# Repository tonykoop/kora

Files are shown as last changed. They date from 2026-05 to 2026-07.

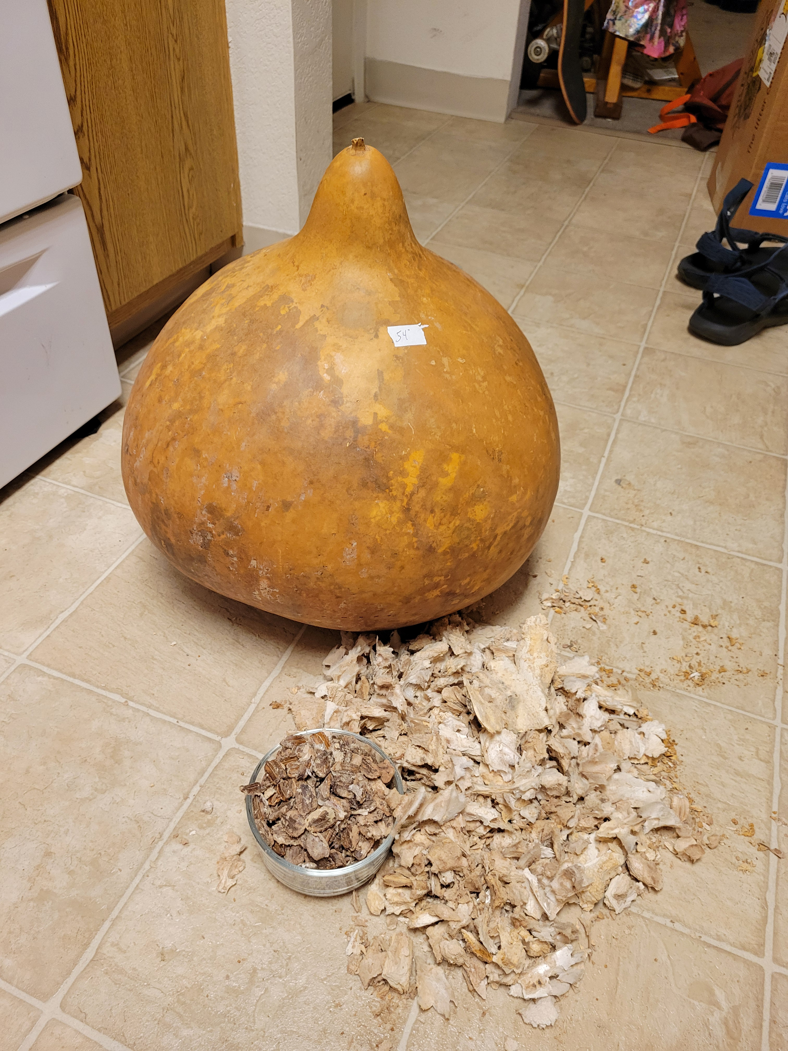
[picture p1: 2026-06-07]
projects/new kora build/20260530_212532.jpg

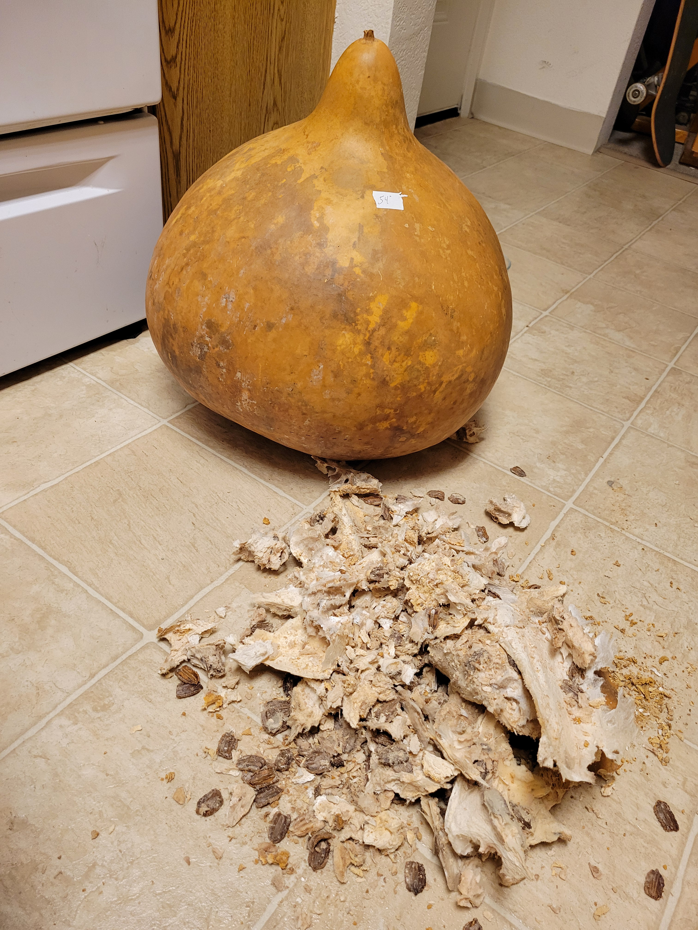
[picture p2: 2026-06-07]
projects/new kora build/20260530_210344.jpg

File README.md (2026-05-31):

# Kora Root-Mode Build Packet

**Status: L2 V5 build-packet candidate**

This repo is a root-mode v4 instrument packet for a 21-string kora-inspired build. It expands the original bare design-table scaffold into a shop-facing packet with design notes, BOM, sourcing assumptions, cut list, validation plan, drawing briefs, RFQ copy, public-site draft, capstone outline, and print packet.

The design source is `kora-design-table.xlsx`. The workbook currently provides the main parametric anchors: bowl diameter and depth, neck length, string lengths, target string tension ramp, nylon density, wound-string density factor, segmented-bowl ring construction, rim geometry, bridge dimensions, and string spacing. Several cell meanings are inferred from formulas rather than workbook labels, so the generated documents mark those assumptions openly.

## Public Release Status

This packet should stay private pending cultural and build-safety review. The kora is not just a generic harp-like mechanism; it belongs to West African Mande/Mandinka musical traditions and is historically associated with jali/griot musicianship. This repo documents an engineering prototype and does not claim lineage authority, traditional build certification, repertoire authority, or permission to market the instrument as culturally authentic.

Before public release, review the provenance language with a knowledgeable cultural advisor or kora player, replace placeholder visuals with measured shop photos or respectful diagrams, and confirm that licensing terms do not accidentally imply cultural ownership.

## Packet Map

- `design.md` - design intent, workbook interpretation, assumptions, cultural provenance notes, and physics model.
- `family-spec.csv` - root build plus lower-risk study variants for future iteration.
- `bom.csv` - make/buy material and hardware list with estimated costs marked as planning estimates.
- `sourcing.csv` - spec-first sourcing table with live price and availability intentionally not verified.
- `cut-list.csv` - rough/final dimensions for segmented bowl, neck, bridge, handles, fixtures, and templates.
- `validation.csv` - dimensional, string-tension, resonance, bridge, joint, safety, and cultural-review checks.
- `string-validation.md` and `string-break-risk.csv` - explicit string break-risk blocker and row-by-row full-stringing gates.
- `assembly-manual.md` - staged build method with hold points before full tension.
- `supplier-rfq.md` - copy/paste RFQ drafts for wood, hide/head material, strings, metalwork, and pickup parts.
- `drawing-brief.md` and `visual-bom-brief.md` - drawing and visual-resource requirements.
- `kora-starter.wl` - starter calculations for string schedule, segmented bowl geometry, and safety plots.
- `risks.md` - red-team concerns and release controls.
- `photo-shotlist.md` - shop and documentation shot list.
- `capstone-deck.md`, `capstone-manifest.json` - presentation outline and artifact inventory.
- `print-packet.md`, `print-packet.html` - print-friendly packet for shop review.
- `site/index.html` - self-contained public build-log draft, currently marked private-review.
- `drawings/`, `cad/`, `cnc/`, `wolfram/` - lightweight technical placeholders and briefs.
- `review-evidence.md` - PR review evidence, local checks, and readiness summary.

## Workbook Snapshot

Current interpreted values from `kora-design-table.xlsx`:

- Bowl outer diameter: 20.3 in.
- Bowl depth: 9.8 in.
- Neck length: 51.2 in.
- String vibrating lengths: 8.7 to 31.1 in.
- Target tension ramp: 8.0 to 14.0 lbf per string.
- Nylon density: 0.04155 lb/in^3.
- Wound-string effective density factor: 2.5x.
- Segmented bowl: 12 segments per ring, 15 deg miter, 0.75 in ring thickness, 14 rings, 168 total segments.
- Bridge height: 6.0 in, bridge width/thickness inputs around 0.75 and 2.5 in, string spacing about 0.273 in by formula.

The current string schedule computes some treble strings at high percent of nylon break strength under the ideal round-string model. Treat the schedule as a design-study table, not a purchase-ready string prescription.

Round 33C/D string validation adds `string-break-risk.csv`: eight nylon rows currently model above the 70 percent prototype break target, nylon string 9 sits at 69.3 percent, and the wound-bass rows still need manufacturer unit-weight or measured mass-per-length data. Full stringing remains blocked until those rows are revised and rechecked.

## Cultural Provenance Notes

External background sources consulted for the provenance framing include the Met Museum collection notes on Mandinka kora objects and Britannica's kora overview. These sources are used only to avoid careless wording; they do not substitute for community review or living maker/player expertise.

- Met Museum kora object notes: https://www.metmuseum.org/art/collection/search/501115
- Britannica kora overview: https://www.britannica.com/art/kora-musical-instrument

## Build Position

This is a conservative hybrid prototype packet:

- A segmented wooden bowl is documented as a calabash substitute, not a traditional-material claim.
- Hide or synthetic head choices are treated as separate resonance and ethics/sourcing decisions.
- A piezo pickup path is planned as optional and should be mechanically isolated from the head until acoustic behavior is understood.
- The neck/body joint, bridge foot, tail anchoring, and head support are treated as primary safety-critical assemblies.

## Readiness

Status: L2 private-review packet. The docs are broad enough for design review, but the packet should not be treated as L3 until cultural review, string-safety revisions, bridge/head proof testing, and measured prototype data are complete.

## License

[CC BY 4.0](LICENSE) - see `LICENSE` for details. Public sharing should wait until the review gates in `risks.md` and `validation.csv` are resolved.

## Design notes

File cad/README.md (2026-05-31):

# `cad/` — CAD assets for the kora-inspired 21-string prototype

## What's here

### SolidWorks source
| File | What it is |
| --- | --- |
| `KOR-000_MasterLayout.SLDPRT` | Parametric MasterLayout part. Source of truth for every driven dimension; design table lives in `KOR-000_MasterLayout.xlsx`. |
| `KOR-000_MasterLayout.xlsx` | Design table (read by SolidWorks). |
| `KOR-000_KoraHarp.SLDASM` | Assembly tying MasterLayout to the part files below. |
| `KOR-000_KoraHarp_ALL_CONFIGS_dimensions.csv` | Flat export of every driven dimension across all configurations. |
| `KOR-000-Gourd.SLDPRT` | Segmented hardwood bowl (168-stave substitute for calabash). |
| `KOR-000-Neck.SLDPRT` | Through-neck spine — continuous structural load path. |
| `KOR-000-Crossbar.SLDPRT` | Neck-to-rim cross brace. |
| `KOR-000-Handle.SLDPRT` | Player hand post (instanced twice in the assembly). |
| `KOR-000-Membrane.SLDPRT` | Hide or synthetic head. |
| `KOR-000-BridgePad.SLDPRT` | Bridge foot pad / cushion against membrane. |
| `KOR-000-Bridge.SLDPRT` | 6.0″ tall notched bridge, two string banks. |
| `KOR-000-Eyebolt.SLDPRT` | Tail anchor (load-rated, rounded contact surfaces). |
| `7815K21_Multipurpose Flanged Sleeve Bearing.SLDPRT` | McMaster-Carr sleeve bearing (×2). |
| `7815K24_High-Strength 932 Bronze Flanged Sleeve Bearing.SLDPRT` | Alternate sleeve bearing for upgrade path. |
| `3032T43_316 Stainless Steel Eyebolt with Nut.SLDPRT` | Stock eyebolt for reference / sourcing. |
| `KOR-000-BasePartTemplate.SLDPRT` | Base part template used to spawn new instances. |
| `kora-parametric-brief.md` | Plain-English brief listing parameters to import from the workbook + CAD warnings. |
| `kora-placeholder.scad` | OpenSCAD placeholder kept for cross-tool reference. |
| `~$…` files | SolidWorks lockfiles — leave alone, they vanish when SW closes the file. |

### glTF export (for the web explorer)
| File / path | What it is |
| --- | --- |
| `KOR-000_KoraHarp/KOR-000_KoraHarp.gltf` | glTF 2.0 JSON metadata. The web explorer (`../explorer.html`) loads this directly via `<model-viewer>`. |
| `KOR-000_KoraHarp/0-N-<part>-N.bin` | One binary buffer per assembly component — 11 buffers total, one per assembly instance (Neck, Gourd, both Handles, Membrane, BridgePad, Bridge, Crossbar, Eyebolt, two Sleeve Bearings). |
| `KOR-000_KoraHarp/leather.jpg` | Texture map for the membrane part. |

## How `explorer.html` consumes the glTF

`explorer.html` (one level up at the repo root) inline-embeds the model as a base64 data URI so the page is fully self-contained — double-click works, no localhost server required.

The packed `KOR-000_KoraHarp.glb` (~971 KB, DRACO-compressed; ~1.3 MB once base64-encoded) lives in a `<script id="kora-glb-data">` tag at the top of the body, and a small `injectCADModel()` function assigns it as the `<model-viewer>` element's `src` on boot. The `images/SolidWorks QuadView.png` four-view shot displays as the poster until the model finishes decoding.

This is the inline-first arrangement (chose 2026-05-17 to make `explorer.html` work as a portable single file). Trade-off: the HTML is ~1.4 MB instead of ~80 KB. Acceptable since the explorer is already not pure-offline (the Wolfram embed iframe + the `model-viewer` JS itself load from CDNs).

If the inline embed gets too heavy later, fall back to either:
- Reference the `.glb` as an external file: `<model-viewer src="cad/KOR-000_KoraHarp.glb">` — requires localhost serving (`python -m http.server 8000` from the kora dir), but trims the HTML back to ~80 KB.
- Reference the multi-buffer glTF directly: `<model-viewer src="cad/KOR-000_KoraHarp/KOR-000_KoraHarp.gltf">` — also requires localhost serving, plus 12 same-origin fetches.

## Re-exporting from SolidWorks → re-packing → re-embedding

When the assembly changes (final details still to come per the v4.3 challenge run), the round-trip is:

1. Open `KOR-000_KoraHarp.SLDASM` in SolidWorks (2024+ has glTF export built in; older versions need an add-in).
2. **File → Save As → glTF 2.0 (`*.gltf`)**. Save into `cad/KOR-000_KoraHarp/` and overwrite the existing files. (`.glb` direct from SolidWorks also works but skips the DRACO-compression step below.)
3. Re-pack the multi-buffer glTF into a single DRACO-compressed `.glb`:
   ```bash
   npx -p gltf-pipeline gltf-pipeline \
       -i cad/KOR-000_KoraHarp/KOR-000_KoraHarp.gltf \
       -o cad/KOR-000_KoraHarp.glb -b -d
   ```
   The `-b` flag asks for a single binary `.glb`; `-d` adds DRACO compression (typically 60–70 % size reduction).
4. Re-base64-embed the new `.glb` into `explorer.html`. Until the instrument-maker skill's generator pass lands, this is a small Python script:
   ```python
   import base64, pathlib
   glb = pathlib.Path("cad/KOR-000_KoraHarp.glb").read_bytes()
   uri = "data:model/gltf-binary;base64," + base64.b64encode(glb).decode()
   src = pathlib.Path("explorer.html").read_text(encoding="utf-8")
   # Replace whatever URI is between the kora-glb-data script tags.
   import re
   src = re.sub(r'(__KORA_GLB_DATA_URI__ = ")[^"]+(")', r'\1' + uri + r'\2', src, count=1)
   pathlib.Path("explorer.html").write_text(src, encoding="utf-8")
   ```
   Once the generator ships, this becomes `python scripts/generate_explorer.py kora`.

## TODOs (non-blocking)

- **Reduce buffer count.** SolidWorks emits one .bin per assembly instance. A `.glb` re-export or a downstream `gltf-pipeline` pass would pack everything into a single binary — smaller wire size, simpler serving.
- **Material assignments.** Current export uses default materials (the only custom map is `leather.jpg` on the membrane). Worth a pass to assign walnut / cedar / brass / nylon-strings PBR materials in SolidWorks Appearances before re-export, so the in-browser model matches the build palette.
- **String geometry.** Strings are present as edges in the SolidWorks model but may render thin / unlit in glTF. A `gltf-pipeline` thicken pass or an explicit cylinder swap would help.
- **Desktop-Wolfram re-author pass.** Independent of CAD, but tracked alongside: `kora-starter.wl` is authored on the WSL Wolfram Engine CLI. A future re-author pass in Wolfram 14.3 desktop (Windows side) could give richer `Manipulate` output before the `wolfram-cloud-sync` Public-Execute publish step.

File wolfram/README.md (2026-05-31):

# Wolfram Notes

Two notebooks live in this folder + repo root:

- `kora-starter.wl` (repo root) — first-pass string and segmented-bowl checks against the workbook string schedule. Workbook-driven.
- `wolfram/kora-acoustic-design.wl` — physics-bounded acoustic design notebook. Computes Helmholtz air resonance, membrane modes, bridge placement coupling, and string schedule from the SolidWorks masterLayout's measured geometry. Use this to sweep chord factor, sound hole size, and bridge offset before committing the masterLayout.

## Running in Wolfram Cloud

1. Open `https://www.wolframcloud.com`, create a new notebook.
2. Paste the contents of `kora-acoustic-design.wl` into a single input cell.
3. Shift+Enter to evaluate. All printouts, tables, and plots render inline.
4. To sweep a parameter, edit the relevant variable in Section 1 (e.g., `chordFactor = 0.50`) and re-evaluate.

## Future notebook exports should include

- revised low-tension mule schedule
- bowl ring geometry table
- measured vs predicted frequency chart
- bridge/head deflection measurements
- post-build tap-test results vs Section 7 predicted Helmholtz and membrane fundamental

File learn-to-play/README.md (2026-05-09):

# Kora — Learn to Play

Starter songbook for Tony Koop's kora build.

## About the kora

The kora is a 21-string West African harp-lute from the Mande tradition
(Gambia, Senegal, Guinea, Mali). It is played with both thumbs and index
fingers; the other fingers grip the handles on either side of the gourd body.

## Tuning

Standard **"Tomora Bara"** tuning in F major pentatonic. Strings are arranged
in two interlocking rows (left and right), not in linear pitch order.

**Left-hand bridge strings (thumb L + index L):**

| String | Pitch |
|---|---|
| L1 | F3 |
| L2 | A3 |
| L3 | C4 |
| L4 | F4 |
| L5 | A4 |
| L6 | C5 |
| L7 | F5 |
| L8 | A5 |
| L9 | C6 |
| L10 | F6 |
| L11 | A6 |

**Right-hand bridge strings (thumb R + index R):**

| String | Pitch |
|---|---|
| R1 | G3 |
| R2 | Bb3 |
| R3 | D4 |
| R4 | G4 |
| R5 | Bb4 |
| R6 | D5 |
| R7 | G5 |
| R8 | Bb5 |
| R9 | D6 |
| R10 | G6 |

(Standard Tomora Bara uses F major pentatonic as the tonal centre; the G and
Bb strings add colour tones from the Bb major scale context.)

## Notation

Staff notation in treble clef. No TAB (the kora is not a fretted instrument).
Melodies are notated at sounding pitch.

## Repertoire

| Folder | Tune | Difficulty |
|---|---|---|
| `00-warmup-scales/f-pentatonic/` | F Pentatonic Scale Walk | Warmup |
| `01-easy/kaira-pattern/` | Kaira Pattern | Easy |
| `01-easy/kora-bells/` | Kora Bells (exercise) | Easy |
| `02-intermediate/tutu-jara-motif/` | Tutu Jara Motif | Intermediate |
| `03-original/river-crossing/` | River Crossing | Intermediate |

## Technique

- Strings are plucked outward (away from the gourd) with the pad of the thumb
  or the nail-side of the index finger.
- Alternating thumb and index finger produces the characteristic kora shimmer.
- Louder notes come from more snap speed, not more force — a sharp, quick
  release produces a bell-like tone.

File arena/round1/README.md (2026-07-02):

# Arena winner: kora (round1)

**Generated model** — the winning Code-CAD Arena candidate for this
instrument (entrant `antigravity-gemini-default`, blind-vote wins 2.0, objective pass-rate 0.5).

This is an AI-generated arena artifact, NOT a measured master or a
validated build packet. See `provenance.json` for the full trial
record. Exported by `makerbench arena export-winners`.

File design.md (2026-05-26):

# Kora Root-Mode Design

## Intent

Create a serious build packet for a 21-string kora-inspired hybrid instrument using `kora-design-table.xlsx` as the parametric design source. The intended first build is a learning prototype, not a declaration of traditional authority or a production-ready commercial instrument.

The packet balances six coupled systems:

- string scaling and tension
- tall notched bridge geometry
- hide or membrane-loaded resonator behavior
- neck load path and tail anchoring
- player ergonomics and hand access
- cultural provenance and public-release sensitivity

## Scope Boundary

This packet documents an engineering prototype rooted in measured and parametric assumptions. It does not claim exact acoustic prediction, traditional craft certification, historical completeness, or permission to present the result as an authentic cultural object. The first release should be private until the cultural-review and safety gates in `validation.csv` pass.

## Workbook Source

Source workbook: `kora-design-table.xlsx`, sheet `Kora`.

The workbook is currently a compact formula sheet without visible human-readable row labels. The following interpretations are inferred from cell values and formulas and should be confirmed before CNC or string purchasing:

| Workbook area | Interpreted meaning | Current value or formula |
| --- | --- | --- |
| `B5` | Bowl outside diameter | 20.3 in |
| `B6` | Bowl depth | 9.8 in |
| `B7` | Neck length | 51.2 in |
| `B8:B9` | Shortest and longest string lengths | 8.7 in, 31.1 in |
| `B10:B11` | Target string tension ramp | 8.0 to 14.0 lbf |
| `B12` | Nylon density | 0.04155 lb/in^3 |
| `B13` | Wound-string effective density factor | 2.5x |
| `B14` | Wound-string start index | 18 |
| `B19:B24` | Segmented bowl setup | 12 segments/ring, 0.75 in ring height, 14 rings, 168 segments |
| `B45:B50` | Rim setup | 16 segments, 11.25 deg miter, 0.5 in rim thickness input |
| `B83:B88` | Bridge setup | 2.5 in/6.0 in/0.75 in inputs, 0.125 in slot clearance, 0.273 in spacing |
| Rows `59:79` | 21-string pitch/length/tension schedule | Mersenne-Taylor formulas |

## Cultural Provenance

The kora is widely documented as a West African 21-string bridge-harp/harp-lute associated with Mande/Mandinka traditions and jali/griot musicianship. The Met Museum collection notes describe the kora as a 21-string instrument from the Mande region with a calabash resonator, hide soundboard, long neck, handles, and a tall bridge. Britannica similarly describes a long hardwood neck passing through a hide-covered calabash resonator, with 21 strings over a notched bridge.

Design language for this repo should therefore use terms such as `kora-inspired prototype`, `engineering study`, and `hybrid build packet`. Avoid wording such as `authentic`, `traditional replica`, `master kora`, or `improved kora`.

Background sources:

- https://www.metmuseum.org/art/collection/search/501115
- https://www.britannica.com/art/kora-musical-instrument

## Governing Models

### Strings

Use the Mersenne-Taylor string model:

```text
f = (1 / (2 L)) sqrt(T / mu)
mu = density pi (diameter / 2)^2
diameter = 2 sqrt(T g / (density pi 4 L^2 f^2))
```

Workbook constants:

- `g = 386.4 in/s^2`
- nylon density = `0.04155 lb/in^3`
- assumed nylon breaking stress = `44600 psi`
- wound-string effective density factor = `2.5x`

Important limitation: percent break is independent of diameter in the ideal round-string model. The current workbook schedule calculates several treble strings near or above practical nylon break targets. This is a safety and design-readiness issue, not a cosmetic issue.

### Resonator

The workbook models a segmented wooden bowl replacing a natural calabash. This changes mass, stiffness, damping, and attachment options. Do not treat the bowl as acoustically equivalent to a traditional calabash without measurements.

The first prototype should measure:

- open bowl air resonance before head installation
- head tap modes after skin or synthetic membrane installation
- bridge-loaded head deflection at staged tension
- microphone response before and after optional piezo installation

### Bridge

The bridge is load-bearing and tone-shaping. It must separate two string banks, maintain string notch spacing, transfer load into the head without tearing it, and avoid rocking under asymmetric playing loads.

Workbook bridge hints:

- height: 6.0 in
- width/thickness inputs: 0.75 in and 2.5 in, to confirm by drawing
- slot clearance: 0.125 in
- string spacing formula: `6 / (21 + 1) = 0.273 in`

### Neck And Load Path

The neck is interpreted as 51.2 in long. A traditional neck passes through the resonator; this hybrid packet should preserve a continuous structural load path rather than relying on the bowl wall alone.

Minimum first-build requirement:

- continuous neck or internal spine through the bowl
- separate tail ring or tail bar with mechanical backup
- no full string load until joint proof-load and bridge-foot tests pass

## Current String Schedule

The schedule below is calculated from the workbook formula pattern and current constants. It is a planning table, not a purchase-ready prescription.

| # | Note | MIDI | Freq Hz | Length in | Type | Target lbf | Diameter in | Percent break |
| ---: | --- | ---: | ---: | ---: | --- | ---: | ---: | ---: |
| 1 | D6 | 86 | 1174.66 | 8.70 | Nylon | 8.00 | 0.0151 | 100.7 |
| 2 | C6 | 84 | 1046.50 | 9.40 | Nylon | 8.30 | 0.0159 | 93.3 |
| 3 | A#5 | 82 | 932.33 | 10.20 | Nylon | 8.60 | 0.0168 | 87.2 |
| 4 | A5 | 81 | 880.00 | 11.00 | Nylon | 8.90 | 0.0168 | 90.4 |
| 5 | G5 | 79 | 783.99 | 12.00 | Nylon | 9.20 | 0.0175 | 85.4 |
| 6 | F5 | 77 | 698.46 | 13.00 | Nylon | 9.50 | 0.0185 | 79.5 |
| 7 | E5 | 76 | 659.26 | 13.80 | Nylon | 9.80 | 0.0187 | 79.8 |
| 8 | D5 | 74 | 587.33 | 15.00 | Nylon | 10.10 | 0.0196 | 74.9 |
| 9 | C5 | 72 | 523.25 | 16.20 | Nylon | 10.40 | 0.0207 | 69.3 |
| 10 | A#4 | 70 | 466.16 | 17.50 | Nylon | 10.70 | 0.0218 | 64.2 |
| 11 | A4 | 69 | 440.00 | 18.50 | Nylon | 11.00 | 0.0222 | 63.9 |
| 12 | G4 | 67 | 392.00 | 19.80 | Nylon | 11.30 | 0.0236 | 58.1 |
| 13 | F4 | 65 | 349.23 | 21.20 | Nylon | 11.60 | 0.0250 | 52.9 |
| 14 | E4 | 64 | 329.63 | 22.50 | Nylon | 11.90 | 0.0253 | 53.0 |
| 15 | D4 | 62 | 293.66 | 24.00 | Nylon | 12.20 | 0.0270 | 47.9 |
| 16 | C4 | 60 | 261.63 | 25.50 | Nylon | 12.50 | 0.0288 | 42.9 |
| 17 | A#3 | 58 | 233.08 | 27.00 | Nylon | 12.80 | 0.0309 | 38.2 |
| 18 | A3 | 57 | 220.00 | 28.20 | Wound | 13.10 | 0.0201 | 92.8 |
| 19 | G3 | 55 | 196.00 | 29.50 | Wound | 13.40 | 0.0218 | 80.6 |
| 20 | F3 | 53 | 174.61 | 30.50 | Wound | 13.70 | 0.0239 | 68.4 |
| 21 | F3 | 53 | 174.61 | 31.10 | Wound | 14.00 | 0.0237 | 71.1 |

Action: reduce treble target tension, lengthen treble scale, change material, or revise pitch assignment before stringing to full pitch. `string-break-risk.csv` is the row-by-row blocker register for this schedule, and `string-validation.md` defines the full-stringing hold points.

## Design Assumptions

- The segmented bowl is a practical shop substitute for calabash, not a cultural or acoustic equivalence claim.
- Neck stock is a straight-grained hardwood blank, final species to be selected for strength and workability.
- Head material is either ethically sourced hide or a synthetic membrane selected after supplier review.
- The first bridge is sacrificial and should be built with extra footprint options for testing.
- The first stringing uses a staged low-tension mule schedule before final target pitches.
- Optional piezo pickup is installed only after the acoustic bridge/head behavior is known.

## Done Criteria

- Workbook labels are clarified or a companion cell map is added.
- Bridge and neck load path are drawn with dimensions, tolerances, and proof-load method.
- String schedule passes percent-break and handling checks.
- Head material and attachment method are sourced with ethical and safety notes.
- Cultural review confirms that public wording is respectful and not overclaiming.
- A measured prototype updates `validation.csv` and the workbook.

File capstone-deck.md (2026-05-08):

# Title

Kora-Inspired 21-String Prototype Root Packet

Private v4.3 challenge run focused on string scaling, segmented resonator construction, bridge geometry, neck load path, ergonomics, and respectful provenance.

# Project Intent

Build a serious engineering packet for a kora-inspired hybrid prototype while preserving humility around cultural context. The packet is intended for private design review, shop planning, and validation before any public build-log release.

# File Map

README, design notes, structured CSVs, sourcing, cut list, validation, assembly manual, RFQ, drawing brief, visual BOM brief, Wolfram starter, risks, photo shotlist, print packet, static site draft, and drawing/CAD/CNC placeholders all live at repo root or first-level folders.

# Workbook Source

The parametric source is `kora-design-table.xlsx`. It provides bowl, neck, string, bridge, and segmented construction values. Some cell meanings are inferred from formulas because the workbook is compact and minimally labeled.

# Governing Physics

The string schedule uses Mersenne-Taylor formulas. Resonator and head behavior are treated as empirical because the segmented wood bowl and membrane/bridge loading cannot be predicted accurately from simple formulas alone.

# String Safety

The current workbook schedule produces high percent-break values in the treble and modeled wound-bass range. This is the largest immediate design risk and requires a low-tension mule schedule before full stringing.

# Resonator And Head

The bowl is modeled as a 20.3 in diameter, 9.8 in deep segmented wooden calabash substitute with 14 rings and 168 segments. It is not presented as a traditional material equivalent.

# Bridge Geometry

The bridge is a tall notched load-transfer part. Its foot, notch spacing, bank separation, and rocking resistance must be validated before tuning targets matter.

# Neck And Tail Load Path

The neck is interpreted from the workbook as 51.2 in long. The first build requires a continuous through-neck or internal spine and a load-rated tail anchor rather than relying on bowl wall strength.

# BOM And Sourcing

The BOM is spec-first. Live prices, stock, and lead times are not verified. Supplier RFQs ask for material traceability, string data, ethical head sourcing, and load-rated hardware.

# Assembly Workflow

Build sequence: workbook audit, segmented bowl, rim/head interface, neck and tail proof-load, bridge prototype, low-tension stringing, measurement, then optional pickup.

# Validation

Validation covers cultural wording, workbook traceability, string safety, miter accuracy, bowl integrity, neck/tail proof load, bridge pressure, tuning, resonator response, ergonomics, and visual placeholder labeling.

# Risks

Primary risks are cultural overclaiming, string breakage, bridge rocking, head tearing, neck/body joint failure, tail anchor cutting, humidity movement, and ergonomics.

# Public Release

This repo should remain private pending cultural review, safety validation, measured prototype data, and replacement of placeholder visuals with owned photos or clearly labeled schematics.

# Next Actions

Label workbook cells, revise the string schedule with real unit-weight data, build a low-tension bridge/head mule, proof-load the neck/tail system, and request cultural wording review.

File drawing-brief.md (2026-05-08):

# Drawing Brief

## Required Drawing Set

1. `drawings/kora-overview.svg` - whole-instrument orthographic overview with bowl diameter, bowl depth, neck length, bridge height, string length range, centerline, and tail anchor.
2. `drawings/bowl-ring-stack.svg` - segmented bowl profile with 14 rings, 12 segments per ring, 15 deg miter note, and depth datum.
3. `drawings/bridge-geometry.svg` - bridge blank, notch spacing, split-bank concept, foot pad, and warning that exact bank layout needs player review.
4. `drawings/load-path-section.svg` - neck/spine, tail anchor, bridge/head load, and bowl wall bypass.
5. `drawings/head-retention-detail.svg` - tacked, laced, or hoop variants after material choice.
6. `drawings/ergonomic-player-view.svg` - seated playing posture with hand posts and wrist-risk zones.

## Technical Standard

Every build-critical drawing should include:

- title block, date, revision, units in inches
- workbook source cell references
- centerline and bridge/tail datums
- dimensions and tolerances separated into fit-critical, load-critical, and visual
- material assumptions
- validation hold points

## Current Status

The SVG files in `drawings/` are lightweight briefs/placeholders. They are not CNC-ready drawings. Use them to coordinate CAD and shop review, then replace them with dimensioned CAD exports before public release or machining.

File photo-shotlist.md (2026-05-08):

# Photo Shotlist

## Provenance And Context

- Workbook open on the `Kora` sheet, showing the design source.
- Printed packet with private-review label visible.
- Material samples labeled as prototype substitutes, not traditional claims.

## Shop Process

- Hardwood stock before cutting.
- Miter sled setup at 15 deg.
- First 12-segment dry-fit ring.
- Full 14-ring stack before shaping.
- Rim dry-fit at 11.25 deg.
- Head material sample and rounded rim contact surface.
- Through-neck/spine dry fit through the bowl.
- Tail anchor proof-load setup with shielding.
- Bridge blank before notching.
- Bridge foot pad test set.
- Partial low-tension stringing.
- Tuner/measurement setup with temperature and humidity note.

## Detail Shots

- Bridge notches and bank separation.
- Tail anchor rounded contact surfaces.
- Head deflection at staged load.
- Neck deflection measurement point.
- Hand post mockup and player reach.
- Optional piezo test placement before drilling.

## Final Review Shots

- Front, side, and rear of private prototype.
- Player seated posture.
- Close-up of labels or notes that mark prototype/cultural-review status.

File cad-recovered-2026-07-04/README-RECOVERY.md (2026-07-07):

# Kora CAD recovery — 2026-07-04

Recovered from git history in the `kora` repo. Nothing was lost; the CAD work was
committed on another branch and captured in a stash, and the working tree had been
switched to `maker/kora-doc-refresh` (== origin/main), which is why the files "vanished".

## Sources
- SolidWorks parts/assemblies below: extracted as REAL binaries from commit
  `da5abb8` ("cad") — the tip of branch **sprint/r4-learn-to-play**.
  Same content is also in stash@{0} (`913e0e9`, "On sprint/r4-learn-to-play: kora edits…").
- `cad/neck_cnc/*` (DXF cut files + packet): from branch **sg2/wolfram-embed-epic196**
  (commit `4cb9c47`, "feat(neck): draft CNC packet").

## What's here — the laminate neck assembly you thought disappeared
- KOR-000_KoraNeck.SLDASM      (1,899,508 b)  <- the neck assembly
- KOR-000_KoraNeck.SLDDRW      (1,822,096 b)  <- its drawing
- KOR-000-LaminateNeck.SLDPRT  (256,275 b)    <- 3/4" hardwood laminate layer
- KOR-000-LaminateTop.SLDPRT   (500,793 b)
- KOR-000-LaminateBottom.SLDPRT(183,555 b)
- MirrorKOR-000-LaminateNeck.SLDPRT (213,595 b)
- KOR-000-Neck.SLDPRT          (150,031 b)
- KOR-000_KoraHarp.SLDASM      (3,655,409 b)  <- the updated harp assembly (main has only 855,946 b)
- KOR-000_MasterLayout.SLDPRT  (189,307 b)
- cad/neck_cnc/  KOR-NECK-*.dxf, neck-cnc-packet.md, neck_cnc_gen.py, neck_cnc_preview.png

## Important note on the newer LFS revision
Branch `sg2/wolfram-embed-epic196` also has NEWER saves of the neck files, but stored as
Git-LFS pointers whose binary objects are NOT in the local LFS cache (need `git lfs pull`
from GitHub, only if they were pushed). Sizes differ from the da5abb8 reals, e.g.:
  KOR-000_KoraNeck.SLDASM  LFS=1,400,680 b   vs  da5abb8 real=1,899,508 b
  KOR-000-LaminateNeck     LFS=  230,928 b   vs  da5abb8 real=  256,275 b
If the da5abb8 versions open correctly and look right, use them. If you specifically want
the last LFS save, run `git lfs pull` (or `git lfs fetch --all`) and diff.

## Neck-length note (your "~49in vs ~63in" concern)
In the readable design-table CSV, the `neck_length_in` equation reads **40in** on both
origin/main and the d016df0 re-save — so that parameter itself didn't change between them.
The big difference is in the binary assembly geometry (main 855KB vs da5abb8 3.66MB).
Open KOR-000_KoraHarp.SLDASM here in SolidWorks to confirm the actual neck length; the
da5abb8 save is the most complete CAD state that exists.

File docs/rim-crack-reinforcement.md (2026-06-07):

# Rim & Crack Reinforcement Plan — Restoration Kora

_Drafted 2026-06-06. Working notes for stabilizing the cracked gourd rim and adding a continuous internal hoop reinforcement around the half-moon crossbar reliefs._

## The problem

The gourd has **two cracks that predate the original build** — evidenced by two reinforcing sutures the original maker sewed in before applying the first cowhide. The serious one **runs from the rim down to the top neck hole**, so it crosses two stress concentrators at once:

- the **bearing edge**, which is under continuous inward pull from the tacked, stretched membrane, and
- the **neck hole**, which carries the leverage of a 51" neck (every bump or lean torques the shell here).

A crack joining those two points is the most likely place for the shell to keep working open over seasons of humidity swings and string tension. It needs (a) a local repair that closes and bonds the crack, and (b) a structural element that carries ongoing **hoop tension** so the crack stops being a hinge.

### Geometry that constrains the fix (from `kora-restoration-measurements.xlsx`, repo-target column)

| Quantity | Value | Source / note |
|---|---|---|
| Gourd OD (widest) | ~20.3 in | B1 |
| Shell depth | ~9.8 in | B4 |
| Rim opening (ID) | **~18 in (confirm — B5 not yet measured)** | estimate from OD minus wall |
| Internal rim circumference | **~57–58 in** at 18.3 in ID | π × ID |
| Target ring bend radius | **~9.0–9.3 in** | ID ÷ 2 |

> Action: measure **B5 (rim ID)**, **B6 (wall thickness)**, and **B7 (rim/bearing width)** before cutting any reinforcement to length. The whole plan keys off the rim ID.

## Material: aluminum flatbar vs. bamboo

Both are sound choices; they trade differently.

**3003 aluminum flatbar — 1/8" × 1" × 72" (McMaster 9134K11).** Your part pick is correct for this job:

- **3003** is the soft, formable alloy — it cold-rolls to a 9" radius without cracking. (5052 is springier but fights you at this radius; 6061 will crack when bent this tight cold. Don't substitute up the strength chart here.)
- 72" length covers the ~58" internal circumference with ~14" to spare for an overlap/scarf joint.
- 1/8" × 1" gives a genuinely stiff hoop; corrosion-proof; bombproof for decades.
- Trade-off: adds mass and stiffness at the rim and can damp shell vibration slightly. At the rim (near a vibration node for the main air resonance) the acoustic penalty is modest, but it is not zero.

**Split/laminated bamboo strips.** The traditional reinforcement seen in the build videos:

- Acoustically closest to the gourd's own impedance — least change to the voice.
- Easy to notch and fit around the reliefs; springy; glues well with epoxy.
- Trade-off: needs **2–3 laminated layers** (bent-lamination over a form) to match the stiffness of the aluminum, is moisture-sensitive, and is fussier to build into a clean full ring.

**Recommendation:** Use the **3003 aluminum ring as the primary hoop**, since the cracked rim is the failure you're actually trying to stop and aluminum is the more reliable structural tie. If you want to protect the voice, you can hold the aluminum **low on the wall** (see Option B below) so it reinforces without sitting right on the bearing edge. Reserve bamboo as the choice only if you decide acoustic purity outranks maximum security — but then commit to a 3-layer lamination.

## The continuity problem: half-moon reliefs

The wooden crossbar is recessed into **two half-moon notches cut into the rim**, so the rim is not a continuous circle — there are two gaps where a full internal ring would collide with the crossbar. Three ways to keep the reinforcement effective:

**Option A — Notch the crossbar, keep the ring continuous (your idea).**
Rout a shallow channel sized to the flatbar cross-section (1/8" deep × 1" wide) into the underside of each crossbar end, so the aluminum ring passes uninterrupted beneath the crossbar.
- ✅ Truly continuous hoop — strongest result.
- ⚠️ Removes material from the crossbar exactly at its bearing points. Mitigated by the fact that you're **re-turning the crossbar anyway** and can leave extra diameter there; and the relief is only 1/8" deep.
- Sequence note: cut these channels **after** you turn the crossbar to final diameter, and dry-fit the ring first.

**Option B — Drop the ring below the reliefs (recommended default).**
Position the aluminum band as a hoop **on the inner wall, below the depth of the relief notches**, so it never intersects the crossbar. The crossbar then ties the rim across the top; the aluminum ring ties the wall just beneath it.
- ✅ No need to compromise the freshly turned crossbar.
- ✅ Keeps metal off the bearing edge → smaller acoustic penalty.
- ✅ Still bridges the lower ~80–90% of the rim-to-neck-hole crack, where it matters most.
- ⚠️ Doesn't reinforce the topmost ~1" of the crack at the bearing edge → handle that locally (see crack repair below).

**Option C — Two C-arcs + crossbar as the tie.**
Run two aluminum arcs that stop short at each relief; let the crossbar span those two gaps as part of the hoop.
- ✅ No crossbar notching, sits at full rim height.
- ⚠️ Load path now depends on the crossbar-to-rim joints being tight — and your reliefs are currently **oversized** for the crossbar, so those joints aren't tight yet. Only viable after the relief gaps are shimmed (see below). Weakest of the three unless the joinery is excellent.

**Pick:** Default to **Option B**. Upgrade to **Option A** only if, after dry-fitting, you decide you want metal right at the bearing edge over the crack. Avoid C unless the crossbar joints end up very tight.

## Crack-specific repair (do this regardless of ring option)

1. **Clean the crack** — work out old glue/dust; lightly key the inner faces.
2. **Close and bond** — work thin epoxy (or thin CA for a hairline) into the crack, clamp/strap it closed, wipe squeeze-out. The original sutures tell you it wants to open — bond it shut before anything else.
3. **Local patch over the crack** — once the planned **interior fiberglass layer** goes in, lay 2–3 extra plies (a "butterfly" patch) bridging the crack on the inside, oriented across the crack line. The full interior glass layer you already planned is itself a continuous reinforcement with no relief problem — it's doing a lot of this work for you.
4. **Top inch of the crack (if Option B):** add a small dedicated patch or a thin glassed-in spline at the bearing edge where the aluminum ring stops short.
5. **Neck-hole end of the crack:** the bushing/collar that fills the 2.25" hole → 1.85" neck gap (below) can be seated to also **clamp the crack closed** at the neck hole. Two birds.

## Fastening the ring

- **Primary bond: epoxy** the aluminum band to the gourd inner wall (scuff and solvent-wipe the aluminum first; West System G/flex or thickened epoxy is forgiving on an irregular gourd wall).
- **Lock the edges** with the interior fiberglass layer lapping over the top and bottom edges of the band — this ties it in far better than fasteners and won't risk splitting the shell.
- **Avoid screws/rivets through the shell** — the gourd wall splits easily and you already have crack problems. If you want mechanical backup, prefer a couple of countersunk brass screws into the **crossbar/neck**, not the shell.
- **Joint in the ring:** scarf or overlap the two ends ~2–3" and bond; locate the overlap **away from the crack and away from the reliefs**.

## Bending the ring (Maker Nexus)

- Roll **1/8" × 1" 3003 the hard way** (1" dimension in the plane of the curve) on the **slip roller** to ~9" radius. 3003 at this thickness rolls easily; sneak up on the radius in passes and check against a plywood template cut to the rim ID.
- Cut a **plywood disc/template to the measured rim ID** first; bend to match it, then dry-fit in the gourd before bonding.

## Related fit gaps (same "fill the mismatch" family — tracked separately)

These aren't reinforcement but the update lumped them in because they're the same shim/bushing problem:

- **Neck hole 2.25" vs. neck shaft 1.85"** → ~0.20" radial gap. Plan: a turned hardwood (or laminated veneer) **collar/bushing** glued to the neck, or a tapered wrap, sized to the hole; seat it to also close the crack at the neck hole.
- **Reliefs oversized for the re-turned crossbar** → same fix: shim the half-moons with thin hardwood pads glued into the notches, or build the crossbar ends up, so the crossbar seats tight (also a prerequisite if you ever consider Option C).

## Open questions / next measurements

- [ ] Measure **B5 rim ID**, **B6 wall thickness**, **B7 rim width** → sets ring length, bend radius, and band height.
- [ ] Decide **Option A vs B** after a dry-fit of the rolled ring.
- [ ] Confirm interior prep order: wire-brush pulp → sand → **crack bond** → fiberglass (with crack butterfly + ring edge-lap) → ring bonded before or during glass?
- [ ] Aluminum vs bamboo final call (defaulting aluminum/Option B).

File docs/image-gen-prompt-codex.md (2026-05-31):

# Image Generation Prompt

Concept visualization only; not fabrication authority.

## Hero Prompt

Photorealistic 3/4 studio product photograph of a kora-inspired engineering prototype with a segmented wooden bowl resonator, hide or synthetic head, long hardwood neck passing through the body, tall notched bridge, two banks of strings, side handles, tail anchoring, and optional piezo service path kept visually secondary. Show the segmented bowl as a luthier adaptation rather than a traditional calabash, with warm oiled wood, taut membrane, simple metal or cord hardware, and respectful private-review presentation. Clean studio background, soft directional lighting, realistic seated-player scale cues, about a 50mm lens, high detail, photorealistic.

## In-Context Prompt

Photorealistic workshop scene of the kora-inspired prototype during bridge and head proof testing, with the bowl supported on padded cradles, the tall bridge seated on the membrane, strings partially installed in two banks, and a builder checking tail anchoring and head deflection. Natural light, respectful cultural framing, no stage costume or authenticity claim.

## Detail / Macro Prompt

Macro photorealistic close-up of the tall notched bridge on the membrane head, two string banks passing over separate notches, segmented wooden bowl rim below, tail anchoring visible in the background, subtle membrane texture and shallow depth of field.

## Negative / Avoid

No text, no watermarks, no authenticity claims, no traditional maker impersonation, no fake logos, no impossible bridge balance, no culturally theatrical staging.

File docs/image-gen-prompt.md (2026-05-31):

# Image-Gen Prompts

Concept image only; not fabrication authority. Do not include cut-ready dimensions, hole locations, or toolpaths.

This is a kora-INSPIRED engineering prototype, not a traditional Mande/Mandinka kora. Renders must read as a respectful hybrid study object: the resonator is an explicitly segmented wooden bowl (a calabash substitute), never a real gourd. No claims of cultural authenticity, no maker marks.

## Hero Prompt

A tall 21-string kora-inspired bridge-harp prototype standing upright as a single finished physical object, photographed at a 3/4 product angle with a ~50mm lens. A large rounded bowl resonator, clearly built from stacked, segmented hardwood rings (visible vertical segment seams and ring courses, like a coopered or turned wooden bowl rather than a natural gourd), forms the body; its open face is closed by a taut membrane soundboard (warm hide-toned or pale synthetic skin) that reads as the drumhead-like top of the resonator. A long straight hardwood neck rises vertically out of and through the bowl, far taller than the body. Two near-vertical banks of pale nylon strings run from the head down to a tall, upright notched wooden bridge that stands on the membrane, the bridge splitting the strings into two parallel ranks left and right of center. Two slender wooden hand-post grips flank the neck where it meets the bowl, for the player's hands. A tail anchor secures the strings at the base. Materials read as fine straight-grained hardwood with a satin oiled finish, natural skin/membrane top, and matte pale strings; honest workshop-prototype craftsmanship rather than ornate decoration. Clean neutral light-grey studio background, soft directional studio light, realistic human-scale cues (an instrument roughly chest-to-head tall when standing), high detail, photorealistic, no text labels.

## In-Context Prompt

The same 21-string kora-inspired prototype staged in a quiet woodworking workshop during build review, resting against a bench or held upright by a seated maker, with the segmented wooden ring-bowl, membrane top, tall neck, twin string banks, and standing notched bridge all clearly visible. Soft natural window light rakes across the workshop, sawdust and hand tools blurred in the background, shallow depth of field keeping the bridge and string banks sharp. Storytelling of an engineering study in progress, not a stage performance; concept visualization only. Photorealistic, warm and honest, no text labels.

## Detail Prompt

Macro close-up of the tall standing notched bridge where it sits on the taut membrane soundboard, showing the upright wooden bridge blade splitting the strings into two parallel banks (left rank and right rank), the individual string notches along the bridge top edge, and the bridge feet pressing into the skin without tearing it. Pale nylon strings angle away in two ranks; the wooden grain of the bridge and the texture of the membrane (hide pores or fine synthetic weave) are crisp under raking side light. Extreme detail, shallow depth of field, no measurements, no text.

## Negative / Avoid

No text/logos/watermarks/fake maker marks, no dimension callouts or measurement lines, no impossible mechanisms, no natural calabash/gourd body (resonator must read as segmented wooden rings), no claims of traditional authenticity; anatomically plausible hands if a player is shown.

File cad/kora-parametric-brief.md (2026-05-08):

# CAD Parametric Brief

## Goal

Build a CAD assembly that keeps the workbook as the source of truth while making the load path visible.

## Parameters To Import

- `bowl_diameter_in = 20.3`
- `bowl_depth_in = 9.8`
- `neck_length_in = 51.2`
- `segments_per_ring = 12`
- `ring_height_in = 0.75`
- `ring_count = 14`
- `rim_segments = 16`
- `bridge_height_in = 6.0`
- `string_count = 21`
- `string_spacing_in = 0.273`

## Required CAD Parts

- segmented bowl ring stack
- rim/head bearing ring
- through-neck or internal spine
- tail anchor and backing block
- bridge with replaceable cap and broad test foot
- hand posts
- optional removable piezo mount

## CAD Warnings

Do not model the shell as load-bearing by default. The string load path should run through the neck/spine and tail anchor. Treat head/head-retention details as provisional until material is chosen.

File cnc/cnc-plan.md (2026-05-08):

# CNC And Fixture Plan

## Current Recommendation

Do not CNC the final bowl or bridge yet. The workbook needs clearer labels, the string schedule needs safety revision, and the neck/tail load path needs a proof-load plan.

## Near-Term Fixture Work

1. Build a miter sled stop setup for 15 deg bowl segments.
2. Cut one 12-segment scrap ring and validate closure.
3. Add a second stop/reference for 11.25 deg rim segments.
4. Laser-cut a bridge notch layout template only after final split-bank geometry is reviewed.
5. Make a bowl sanding/truing jig for the 20.3 in diameter profile.

## Toolpath Constraints

- No toolpath should remove material from the neck/spine load path without a revised structural drawing.
- Bridge notch toolpaths must leave rounded/polished string contact surfaces.
- Templates should include centerlines, registration holes, and revision labels.

## CNC-Ready Exit Criteria

- dimensioned CAD drawing exists
- workbook cell map is complete
- material is selected
- fixture dry-run completed on scrap
- validation hold points are printed and signed off

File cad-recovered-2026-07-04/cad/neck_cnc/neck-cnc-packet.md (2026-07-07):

# Kora Neck — CNC Packet (DRAFT)

CNC machining plan for the new kora neck. Strings enter the **front** face, route
through an internal **back channel** (closed by a cover plate), and wrap
**side-mounted guitar tuner** posts. Flat-backed rectangular blank.

> **Status: DRAFT.** Three inputs must be set before cutting — see *Open variables*.
> Geometry is parametric in `neck_cnc_gen.py`; edit the header and re-run.

## Confirmed from the repo

- **21 strings**, two rows, bridge spacing 0.273 in (`design.md`).
- Strings alternate to opposite rows → **11 on the right, 10 on the left** (adjacent
  pitches on opposite hands, standard kora practice).
- Hole stations seeded from the speaking-length schedule: **S1 (treble) sits low,
  S21 (bass) sits high**, spanning **22.4 in** up the neck.
- `string_count = 21`, `neck_length_in = 40` (MasterLayout equations).

## Operations (5 setups)

1. **Front-face drill** — `KOR-NECK-Front-Drill.dxf`: 21 holes Ø0.16 in, two rows at
   ±0.35 in, at the staggered stations. Drill from the front; they break into the channel.
2. **Back channel rout** — `KOR-NECK-Back-Channel.dxf`: 0.75 in wide × 0.75 in deep
   pocket down the back centerline (leaves a 0.50 in front wall that the string holes
   pass through). Rout in multiple depth passes.
3. **Cover plate** — `KOR-NECK-Cover.dxf`: caps the channel; #4 screws on 4 in pitch.
4. **Side tuner bores L/R** — `KOR-NECK-Side-RIGHT.dxf`, `KOR-NECK-Side-LEFT.dxf`:
   cross-bores from each side into the channel at each string's station (post bore +
   bushing counterbore + mounting-screw pilot). **Dims are placeholders.**
5. Profile/round the blank to final neck shape by hand after machining.

## Open variables (set these, then re-run)

| Variable | Placeholder | Source |
|---|---|---|
| `POST_D` | 0.250 in | measured tuner post bore |
| `BUSHING_D` | 0.395 in | tuner front bushing/ferrule |
| `SCREW_OFF` / `SCREW_D` | 0.50 / 0.090 in | tuner baseplate screw |
| `BORE_Z` | T−0.40 in | post depth into channel |
| `W_NECK` × `T_NECK` | 1.50 × 1.25 in | your finished neck cross-section |
| `stations[]` | from string lengths | **reconcile to real bridge datum** |

The single most important reconciliation: the hole stations here assume station ≈
speaking length up from a `DATUM` of 4 in. Your `Neck Face` sketch in
`KOR-000_MasterLayout` already carries longitudinal positions — confirm which governs
(measure where each string actually crosses the neck given the real bridge height and
position over the gourd) before committing to drill centers.

## Machining notes

- Do **front holes and side bores before** routing the channel away too much material —
  keep the blank rigid for cross-drilling; or rout channel last from the back.
- Side bores are cross-axis: use an indexed fixture or drill press for the L/R faces;
  the DXFs give you exact station coordinates for a fence stop.
- Flat back simplifies workholding — machine all features on the rectangular blank,
  then shape the rounded neck profile and headstock taper by hand/spokeshave.
- Verify the 0.50 in front wall is enough for your hardwood + string tension; thicken
  by reducing `CH_DEPTH` if the species is soft.

## Regenerate

```
python3 neck_cnc_gen.py     # writes 5 DXFs
```

Files: `neck_cnc_gen.py`, the 5 DXFs, `neck_cnc_preview.png`.

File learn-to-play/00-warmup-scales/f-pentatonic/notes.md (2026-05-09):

# F Pentatonic Scale Walk

**Provenance:** Original exercise.

**Scale:** F major pentatonic (F A C F) + G major pentatonic colour (G Bb D G).
Together these two rows cover the full standard Tomora Bara tuning palette.

**How to play:**
- First section (bars 1–2): right-hand index finger walks up the left bridge
  strings F–A–C–F, then back down. Mirror with right bridge G–Bb–D–G in bars 3–4.
- Second section: practice the interlock — alternate left-bridge (F–A–C) and
  right-bridge (G) strings on each beat.

**Practice tips:**
- The kora characteristic sound comes from the *alternation* between the two
  string rows. Even at warmup speed, try to feel the left–right–left–right
  hand exchange.
- Keep your grip handles loose — tension in the grip tightens the pluck and
  kills resonance.

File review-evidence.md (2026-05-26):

# Review Evidence

- Mode: instrument-maker v4.3 root-mode packet.
- Source reviewed: existing packet files plus `kora-design-table.xlsx`.
- Packet readiness: L2 private-review packet. Cultural review, string-safety revisions, bridge/head load tests, actual string unit weights, and measured acoustic data remain pending.
- Round 33C/D string slice: `string-validation.md` and `string-break-risk.csv` make the high percent-break blocker explicit before any full-stringing or build-ready claim.
- Local checks to run before PR: `git diff --check`, `python3 -m csv string-break-risk.csv`, `python3 -m csv validation.csv`, and `jq . capstone-manifest.json`.
- Review focus: README/design language keeps the build framed as a kora-inspired engineering prototype, and `validation.csv` plus `string-break-risk.csv` keep public-release and full-stringing gates open.

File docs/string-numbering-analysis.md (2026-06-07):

# String Numbering Analysis — Restoration Kora

_Drafted 2026-06-06, from the measured speaking lengths in the restoration measurements (String Schedule). Addresses the open worry: "I'm not sure I attributed string lengths to the proper number and key."_

## Tony's measuring convention

- 21 strings total: **11 on the left bank (odd numbers 1–21), 10 on the right bank (even numbers 2–20)**.
- Top-left string = #21 (longest), bottom-right = #2.
- Speaking lengths recorded. All strings measured **0.026″** uniform diameter (pitch is set by length/tension, not gauge); material and tuning-ring positions not yet recorded.
- Missing strings: **#1 (D6), #2 (C6), #8 (D5)** — all at the high/short end.

## Measured speaking lengths (inches)

| Bank | Strings → lengths |
|---|---|
| Left (odd) | 1: _missing_, 3: 14.4, 5: 17.25, 7: 19.75, 9: 23, 11: 25, 13: 27.1, 15: 29.2, 17: 30.25, 19: 31, 21: 31.5 |
| Right (even) | 2: _missing_, 4: 10.25, 6: 11.4, 8: _missing_, 10: 13.8, 12: 16, 14: 21.75, 16: 24.4, 18: 26.2, 20: 28.3 |

## Findings

**1. Within each bank, the numbering is internally consistent.**
Both banks increase monotonically in length with string number (Left 14.4→31.5, Right 10.25→28.3). No string sits out of order within its own column. The "top = longest" convention held.

**2. The two banks do NOT interleave into the canonical kora pattern.**
A standard 21-string kora alternates banks evenly by pitch: sorted shortest→longest, the banks read `L R L R L R …`. Tony's instrument, sorted by measured length, reads:

```
R R R L R L L R L R L R L R L L L L      (measured)
L R L R L R L R L R L R L R L R L R L R L (canonical)
```

The right bank clusters at the short end; the left bank clusters at the long end.

**3. The mismatch is systematic, not random — pointing to geometry, not mislabeling.**
Deviation of measured from the reference schedule:

- **Left bank: uniformly longer**, +0.4″ to +6.8″, bowing out to a maximum in the middle of the bank.
- **Right bank: uniformly shorter**, −0.75″ to −3.8″.

A random numbering error would scatter; this smooth, banded offset is the signature of an **asymmetric instrument** — an offset bridge or different tuning-ring heights on the two sides give one bank systematically longer speaking lengths. Consistent with the eBay listing ("Kora-**style** … Tribal Folk Decor"); this piece likely never had a true symmetric Mandé tuning.

## Recommendation

- **Do not back-solve canonical string numbers from the old lengths.** It's restringing with a fresh set, so the reference schedule (Ref Note column, D6→F3) is the *target* — tune the new strings to pitch rather than trying to reconstruct the old assignment.
- **Use the measured old lengths only for geometry**: bridge-notch spacing and tail-anchor order. They are a sanity check, not the authority on numbering.
- **Cover the missing high strings** in the new set: #1 D6, #2 C6, #8 D5.
- **Reference typo resolved → #21 = F2.** The Ref Note column originally listed `F3` for both #20 and #21 (an octave typo). In Mande/Silaba tuning the lowest left-bank string — the *Timbamba* / *Bakumba* — is tuned to the tonic **one octave below the base F3**, i.e. F2, not a further scale step (E3). The physical evidence corroborates: #21 is a heavy **4-strand braid** vs the **2-strand twist** on #20, exactly what an octave-drop bass string needs.

## Data location

The measurements now live as CSV under `kora-restoration-measurements/` (one file per workbook sheet) — text format that survives the file-sync issues the `.xlsx` hit and diffs cleanly in git. `string-schedule.csv` is the current source of truth for string data.

## Open items

- [x] Corrected #21 to F2 (Mande bass tonic); recorded 0.026″ diameters and braid/twist notes in `string-schedule.csv`.
- [ ] Final tuning target on restring: standard Mande/Silaba (F major), restrung so the two banks alternate in the proper zigzag interleaving.
- [ ] On restring, also record material and tuning-ring position per string (still blank).
- [ ] Re-enter any newer Dimensions / Condition-tab edits if they didn't survive the `.xlsx` sync (CSVs were converted from the last good commit).

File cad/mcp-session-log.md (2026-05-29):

# MCP / External-Tool Session Log

V5 provenance record for artifacts generated or modified by external tools.

| session_id | tool | input_authority | outputs | role | authority_result | review_status | notes |
|---|---|---|---|---|---|---|---|
| cindy-r1-2026-05-29 | claude-code | kora-design-table.xlsx | visual-output-register.csv | artifact_registration | pending_measurement | self_checked | V5 surface pass: registered all existing artifacts. kora-placeholder.scad was pre-existing; registered as CAD-001. |

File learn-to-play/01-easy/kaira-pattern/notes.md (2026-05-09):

# Kaira Pattern

**Provenance:** "Kaira" is one of the foundational pieces of the Mande griot
repertoire, associated with peace and calm. The melodic pattern here is drawn
from the traditional kumbengo (ostinato) basis. Traditional/folk — public domain.

**Range:** F3–F5.

**Performance context:** In the griot tradition, Kaira is played at celebrations,
naming ceremonies, and during moments of praise. The repetitive nature is
intentional — the kumbengo ostinato creates a hypnotic groove that supports
improvisation and song.

**Practice tips:**
- Play this slowly at first (♩=60) and let each string ring fully before plucking
  the next.
- The G (right bridge) in bar 2 and bar 6 creates a slight harmonic tension
  against the F-centre — that's the jazz-like colour of the kora.
- Once you can loop the pattern smoothly, try adding a simple thumb drone on F3
  every 4 beats.

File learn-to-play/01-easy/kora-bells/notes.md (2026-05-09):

# Kora Bells

**Provenance:** Original exercise.

**Purpose:** This exercise isolates the highest strings of each bridge row
(F5/C5 left-bridge; G5/D5 right-bridge) to develop consistent tone in the
upper register where the kora's bell-like quality is most prominent.

**How to play:**
- Bars 1–4: play the high strings of the left bridge (f, c) then right bridge
  (g, d) alternating.
- Bars 5–8: mix the two bridges in a single phrase, practising the hand switch.

**Practice tips:**
- Higher strings require less pluck force — the shorter string length makes
  them more sensitive. Keep your snap light and even.
- Let every note decay fully before the next pluck. If you hear muddiness,
  you're plucking before the previous string has rung out.

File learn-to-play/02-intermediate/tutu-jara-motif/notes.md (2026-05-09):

# Tutu Jara Motif

**Provenance:** Drawn from the traditional Mande piece "Tutu Jara" (Lion of
Tutu), a classic griot composition. This is a simplified motif from the
kumbengo line. Traditional/folk — public domain.

**Range:** F3–F5. 12/8 compound feel — think "ONE-and-a, TWO-and-a."

**Why this is intermediate:**
- 12/8 compound meter requires internalising a triplet subdivision while
  maintaining a steady pulse.
- The interlock between the F-pentatonic left bridge and the G/D right bridge
  becomes more complex here — you need to switch hands mid-phrase.

**Performance notes:**
- In the griot tradition, this piece is often played in praise of a noble
  hunter. The 12/8 feel gives it a swaying, processional quality.
- The long held tones (F9 = dotted quarter note × 3) should resonate fully
  before the next phrase begins — use this space to re-position your hands.

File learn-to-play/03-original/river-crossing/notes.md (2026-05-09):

# River Crossing

**Provenance:** Original composition by Heifer Zephyr for this kora build.
MIT licensed — free to perform, record, and arrange.

**Designed for:** Tony Koop's kora (Tomora Bara tuning, F pentatonic).

**Range:** F3–G5. Uses both bridge rows throughout.

**Form:** AABB.

**Character:** A flowing, meditative piece — the title evokes the moment of
hesitation before stepping into a river current, then the decision to cross.

**Practice tips:**
- The A section alternates steadily between left and right bridge strings.
  Feel the shimmer as the two rows interlock.
- The B section has a longer arc — the melody rises to G5 in bar 14 before
  resolving back down to F3.
- At ♩=84 this should breathe naturally. Don't rush the long F8 at the end
  of each section — it's the river, not the crossing.

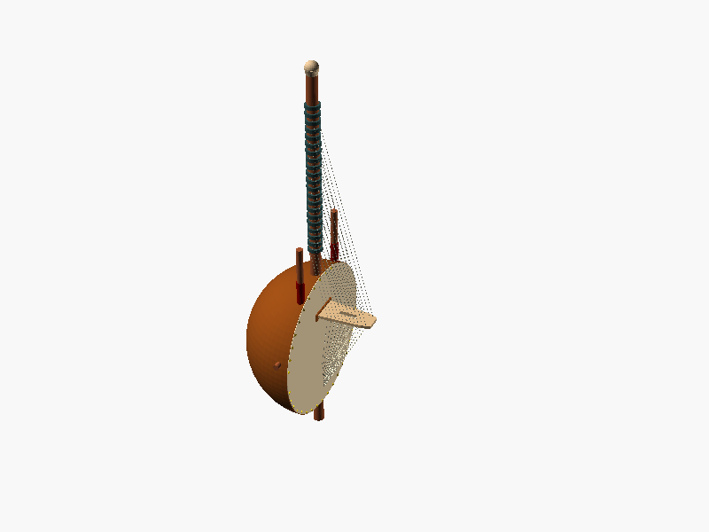
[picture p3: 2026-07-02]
arena/round1/kora-arena-winner.png

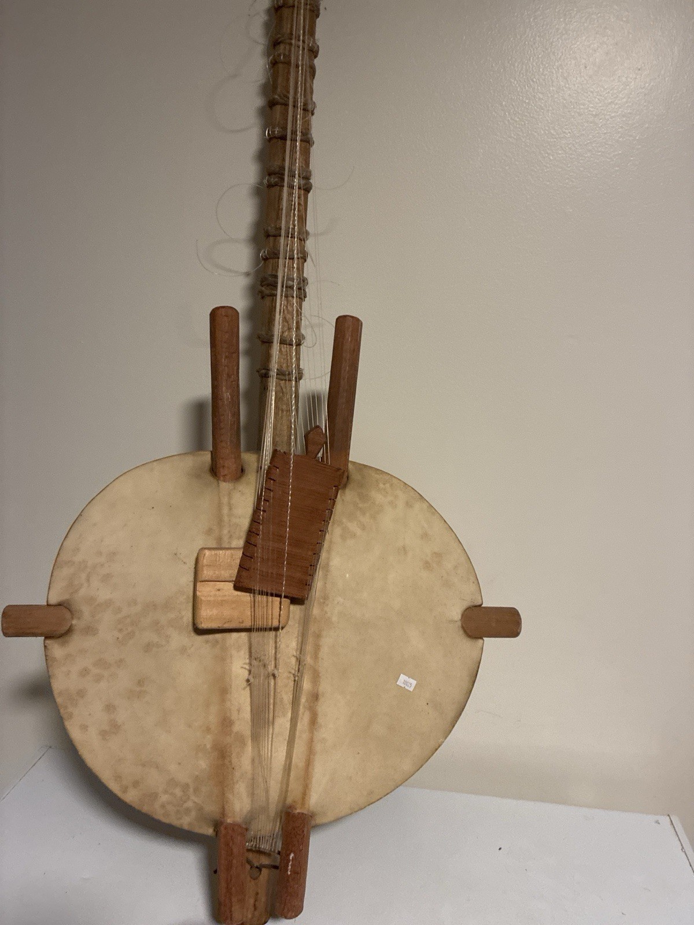
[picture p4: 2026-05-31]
projects/Large 50” African Kora Style String Instrument Gourd Harp Tribal Folk Decor _ eBay_files/s-l1600_003.jpg

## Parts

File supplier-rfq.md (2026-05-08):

# Supplier RFQ Drafts

## Hardwood Supplier

Hello,

I am sourcing material for a prototype stringed instrument with a segmented wooden resonator bowl and a long through-neck/spine. Please quote suitable straight-grained hardwood stock for:

- segmented bowl strips, enough for 168 small mitered segments plus scrap/testing
- one straight neck blank at least 52.5 x 2.25 x 1.0 in before milling
- one dense bridge blank at least 7.0 x 3.0 x 1.0 in
- optional hardwood dowel or turning stock for two hand posts

Important requirements: dry stable stock, minimal runout for the neck, no cracks/checks in load-bearing pieces, and clear species identification. Please include unit price, board-foot price, lead time, shipping estimate, and any recommended substitute species.

## Head Material Supplier

Hello,

I am building a private prototype of a kora-inspired 21-string instrument and need a head membrane for a 20.3 in diameter resonator, with additional wrap/tension allowance. Please quote ethically sourced hide options and any synthetic alternatives suitable for a plucked-string bridge load.

Please include material origin or traceability where available, thickness range, recommended mounting method, humidity sensitivity, lead time, and care instructions. I am not presenting this as an authentic traditional build; this is a documented engineering prototype.

## String Supplier

Hello,

I need help developing a safe prototype string schedule for a 21-string kora-inspired instrument. Current vibrating lengths range from 8.7 to 31.1 in. The preliminary target tension range is 8 to 14 lbf, but the current model indicates the treble schedule may be too close to nylon break strength.

Can you quote nylon and wound strings with manufacturer unit weight or tension data for the following note/length study? I am looking for a safe prototype set and am open to lowering tension or changing pitch targets.

Please include unit weight, recommended tension range, breaking/tensile data if available, diameter, price per string, lead time, and substitution recommendations.

## Metal Hardware Supplier

Hello,

I am sourcing a rounded steel or brass tail anchor ring/bar for a 21-string prototype. The hardware must have no cutting edges and should be load-rated well above the expected total string load. Please quote suitable rings, bars, or custom-bent options, including material, finish, rated load, dimensions, price, lead time, and shipping.

## Electronics Supplier

Hello,

I am sourcing optional removable piezo pickup parts for an acoustic prototype. Please quote piezo disk or film elements, shielded lead wire, 1/4 in output jack hardware, and any low-noise mounting recommendations. This is optional and will be installed only after acoustic load testing.

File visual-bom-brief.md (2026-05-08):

# Visual BOM Brief

## Goal

Create a one-page visual BOM plate that helps a builder understand the kora-inspired prototype at a glance without implying that placeholder imagery is traditional or source-authoritative.

## Layout

- Header: `Kora-Inspired 21-String Prototype - Visual BOM`
- Large whole-instrument diagram from `drawings/kora-overview.svg`
- Exploded callouts for bowl, head, neck/spine, bridge, strings, hand posts, tail anchor, optional piezo
- Table grouped by subsystem: resonator, structure, bridge, strings, electronics, fixtures, finish
- Footer note: `Prototype engineering packet; cultural and safety review required before public release.`

## Image Policy

- Use actual shop photos once available.
- Use generated or schematic images only when labeled `concept placeholder`.
- Do not use photos of specific traditional makers' instruments as build references unless permission and attribution are clear.
- Do not present the segmented wooden bowl as a traditional calabash.

## Required Replacement Photos

- hardwood stock and ring segments
- dry-fit ring stack
- head material sample
- neck/spine proof-load setup
- bridge foot test
- partial low-tension stringing
- final private prototype, if built

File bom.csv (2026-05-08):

item_id | subsystem | part_name | qty | unit | material_spec | dimensions_or_spec | make_buy | estimated_cost | cost_basis | risk_note
BOWL-001 | resonator | segmented bowl staves | 168 | pcs | straight-grained hardwood strips | 12 segments per ring x 14 rings x 0.75 in ring height | make | 120 | planning estimate from hardwood stock allowance | Species and wall thickness affect tone and strength.
BOWL-002 | resonator | rim ring segments | 16 | pcs | hardwood | 20.3 in diameter rim system with 11.25 deg miter | make | 25 | planning estimate | Rim must avoid head tearing and provide even bearing.
BOWL-003 | resonator | head membrane | 1 | ea | ethically sourced goat/calf hide or synthetic substitute | 20.3 in head plus wrap allowance | buy | 80 | planning estimate | Material choice has cultural and ethical implications.
BOWL-004 | resonator | head tacks or lacing hardware | 1 | set | stainless/brass tacks or cord system | sized to rim and head method | buy | 35 | planning estimate | Fastener spacing must not split rim.
NECK-001 | structure | through-neck blank | 1 | ea | hard maple/walnut/mahogany or equivalent straight-grain hardwood | 51.2 x 2.0 x 0.75 in interpreted minimum | make | 55 | planning estimate | Primary load-bearing member.
NECK-002 | structure | tail anchor ring/bar | 1 | ea | steel or brass with rounded contact surfaces | sized for 21 strings plus safety margin | buy | 30 | planning estimate | Anchor failure is high-energy risk.
BRDG-001 | bridge | notched bridge blank | 1 | ea | dense hardwood with replaceable saddle cap | 6.0 in high x 2.5 in wide x 0.75 in thick interpreted | make | 20 | planning estimate | Bridge rocking and head denting are primary risks.
BRDG-002 | bridge | bridge foot pad or cushion | 1 | ea | leather/cork/felt test stack | footprint derived estimate | buy | 12 | planning estimate | Needed to distribute load into membrane.
HAND-001 | ergonomics | player hand posts | 2 | ea | hardwood dowels or turned handles | diameter and reach to confirm from player mockup | make | 18 | planning estimate | Must not weaken bowl/head joint.
STR-001 | strings | nylon treble/mid strings | 17 | lengths | nylon monofilament or harp string gauges | 0.015-0.031 in workbook-calculated diameter range | buy | 45 | planning estimate | Current treble percent-break is too high; revise before full tension.
STR-002 | strings | wound bass strings | 4 | lengths | wound nylon/metal-core equivalent density study | 0.020-0.024 in workbook-calculated effective range | buy | 60 | planning estimate | Effective density model must be matched to real strings.
ELEC-001 | electronics | piezo pickup element | 1 | ea | passive piezo disk or under-bridge film | prototype only after acoustic tests | buy | 15 | planning estimate | Do not install before bridge/head pressure is understood.
ELEC-002 | electronics | output jack and cable hardware | 1 | set | 1/4 in jack with shielded lead | side or tail location to be confirmed | buy | 12 | planning estimate | Drilling location must avoid stress path.
JIG-001 | fixtures | miter sled setup | 1 | set | table saw sled with 15 deg and 11.25 deg references | for bowl and rim segments | make | 30 | planning estimate | Fixture error multiplies across 184 segments.
JIG-002 | fixtures | bridge alignment template | 1 | ea | laser-cut acrylic or plywood | 21 slots at about 0.273 in spacing | make | 10 | planning estimate | Template must match final bridge/string bank layout.
FIN-001 | finish | finish system | 1 | set | oil/shellac/waterborne finish compatible with hide/head contact | shop-selected | buy | 35 | planning estimate | Finish must not contaminate glue or head bearing surfaces.

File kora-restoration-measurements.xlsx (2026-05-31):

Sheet: Instructions
 | Kora Restoration - Measurement & Documentation Workbook
 | eBay instrument: Large 50" African Kora-style gourd harp. Capture before disassembly. Units: inches.
How to use this workbook
 | Dimensions | Main capture sheet, organized by subsystem. Fill the yellow 'Measured (in)' column. The blue 'Repo Target (in)' column shows the value from your own build spec (kora-design-table / CAD) for comparison - it is NOT what this instrument 'should' be, just a reference point.
 | String Schedule | One row per string. Record speaking length, total length, caliper diameter, which bank (left/right of bridge), and the tuning-ring position. Reference lengths/notes are from your design.md schedule.
 | Photo Log | Shot list for documenting condition and geometry. Tick 'Done' and note the filename so photos map to measurements.
 | Condition & Restoration Log | Record what you find and the planned action per component. Your stated scope (cowskin, strings, tacks, anchor, sanding, finish) is pre-listed.
Measuring conventions
 | Pick a datum first | Define a single reference point and direction before measuring so everything is repeatable. Suggested: neck-to-gourd entry point = 0, measure UP the neck toward the head and DOWN toward the tail/anchor separately. Note your datum in the Notes.
 | Measure before AND after destring | String tension distorts the skin, bridge lean, and neck. Capture loaded geometry first (bridge height, skin doming, neck angle), then re-measure unloaded after removing strings.
 | Take 3 readings | For anything load-bearing or tapered (neck/handle/crossbar diameters, gourd diameter), measure in 2-3 places and record all; note location. Diameters are rarely round - record max and min.
 | Caliper vs tape | Calipers for diameters, thicknesses, spacing, string gauges. Tape for lengths and the gourd circumference. Record string gauges in thousandths of an inch.
 | Trace what you can't measure | Before removing the skin, trace the gourd rim outline, the bridge footprint, and the tack pattern onto paper or photograph against a ruler. These are nearly impossible to reconstruct later.
 | Count and map strings | Photograph the bridge straight-on and number the strings/notches L and R before loosening anything. Note the order they attach at the anchor.
 | Label as you disassemble | Bag and label tacks, rings, and the bridge/foot. Note original tack spacing and count - your new tack pattern should match unless you decide otherwise.
Legend
 | Yellow cell | You fill this in (your measurement).
 | Blue cell | Reference value from your repo build spec - read-only comparison.

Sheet: Dimensions
Dimensions - by subsystem
ID | Dimension | How to measure | Repo Target (in) | Measured (in) | Date | Notes / location
A. Overall / Datum
A1 | Overall length (head tip to tail/anchor) | Tape, instrument laid flat. The listing calls it ~50 in. | 50.000
A2 | Neck length (gourd entry to head tip) | Tape along neck from where it exits the gourd to the tip. | 51.200
A3 | Neck length (gourd entry to tail exit) | Distance the neck/spine protrudes past the gourd at the tail.
A4 | Datum description | Write where your 0 point is and measurement direction.
B. Gourd / Calabash Resonator
B1 | Gourd outside diameter - widest | Tape or large caliper across the widest point of the bowl. | 20.300
B2 | Gourd outside diameter - 90 deg to B1 | Measure perpendicular; gourds are not round.
B3 | Gourd circumference (max) | Tape around the fullest part of the gourd.
B4 | Shell depth (rim plane to deepest point) | Straightedge across the open face, measure down to the back. | 9.800
B5 | Soundboard opening diameter (rim ID) | Across the cut opening where the skin attaches.
B6 | Shell wall thickness | Caliper at the cut rim; sample 3-4 spots, record range.
B7 | Rim width / bearing surface | Flat width the skin bears on at the rim.
C. Soundboard (Cowhide / Membrane)
C1 | Skin diameter on face (visible) | Across the stretched skin on the front face.
C2 | Skin diameter incl. wrap-over | Add the amount folded over the rim to the back; sets new hide blank size.
C3 | Hide thickness | Caliper on a wrap-over edge or offcut; sample several spots.
C4 | Wrap-over depth (how far skin folds back) | From rim edge to where the skin terminates / is tacked.
C5 | Soundboard dome height (loaded) | Straightedge across rim, measure skin rise at center, strings ON.
C6 | Sound hole(s) present? size + position | Some koras have a side port. Diameter and location from rim.
D. Tacks / Rim Attachment
D1 | Tack count (total) | Count around the full rim before removing skin.
D2 | Tack spacing (center to center) | Caliper between adjacent tack centers; record typical + range.
D3 | Tack head diameter | Caliper across a tack head.
D4 | Tack shank diameter | Caliper on a removed tack shank.
D5 | Tack length | Length of a removed tack.
D6 | Tack ring setback from rim edge | Distance from rim edge to tack line.
E. Neck
E1 | Neck diameter at head (top) | Caliper near the tuning-ring area; note round/oval.
E2 | Neck diameter at gourd entry | Caliper where it enters the gourd.
E3 | Neck diameter at tail exit | Caliper where it exits at the tail.
E4 | Neck cross-section shape | Round / oval / faceted - describe.
E5 | Neck-to-face angle (string break angle) | Angle of the neck relative to the soundboard plane; protractor or photo.
E6 | Tuning-ring zone length | Length of neck occupied by the tuning rings.
F. Tuning Rings (leather)
F1 | Tuning ring count | Should equal string count. Count them. | 21.000
F2 | Ring band width | Width of one leather ring along the neck.
F3 | Ring spacing (center to center) | Caliper between adjacent rings; record range top-to-bottom.
F4 | Topmost ring position (from head tip) | Distance from head tip to first ring.
F5 | Bottommost ring position (from head tip) | Distance from head tip to last ring.
F6 | Ring material / cord diameter | Leather thong / cord - measure thickness.
G. Bridge
G1 | Bridge height (overall) | Caliper/ruler, foot to top edge. | 6.000
G2 | Bridge width (across, string-bank direction) | The dimension carrying the notches. | 2.500
G3 | Bridge thickness | Caliper through the bridge. | 0.750
G4 | Notch count - left bank | Count notches on the left side.
G5 | Notch count - right bank | Count notches on the right side.
G6 | String spacing on bridge (notch to notch) | Caliper between adjacent notches; record typical. | 0.273
G7 | Gap between left/right banks (center web) | Width of the solid center separating the two banks. | 0.125
G8 | Notch depth | Depth a string seats into a notch.
G9 | Bridge foot footprint (L x W) | Footprint where the bridge meets the skin (the lighter wood foot).
G10 | Bridge foot / pad thickness | Thickness of the foot block / any pad under the bridge.
G11 | Bridge position on face (from neck side) | Distance from neck entry to the bridge foot.
G12 | Bridge lean / tilt (loaded) | Angle of bridge off vertical with strings on.
H. String Anchor / Tailpiece
H1 | Anchor type | Iron ring / wood bar / cord loop - describe.
H2 | Anchor overall length / diameter | Size of the anchor piece.
H3 | Anchor position (from gourd / tail) | Where it sits relative to the tail exit of the neck.
H4 | Number of attachment points | How many strings tie off / how they're grouped. | 21.000
H5 | Anchor-to-bridge distance | Along the face, anchor to bridge foot.
I. Handles / Hand Posts (uprights)
I1 | Handle count | Typically 2 upright posts. | 2.000
I2 | Handle length (above face) | Exposed length of each post.
I3 | Handle diameter | Caliper; note taper if any.
I4 | Handle spacing (between posts) | Center-to-center across the face.
I5 | Handle insertion depth / how mounted | How posts attach to gourd/neck.
J. Crossbars / Side Bars (through gourd)
J1 | Crossbar count | The dowels protruding from the sides of the gourd.
J2 | Crossbar protrusion length (each side) | How far each end sticks out.
J3 | Crossbar diameter | Caliper; note taper.
J4 | Crossbar full length (through gourd) | If removable / measurable end to end.
J5 | Crossbar height position on gourd | Where on the gourd the bar passes (from rim).

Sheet: String Schedule
String Schedule - one row per string (number L-to-R at the bridge, top bank first)
String # | Bank (L/R) | Ref Note | Ref Length (in) | Measured speaking length (in) | Measured total length (in) | Measured diameter (in) | Material | Tuning-ring # / pos (in) | Condition | Notes
1 |  | D6 | 8.70
2 |  | C6 | 9.40
3 |  | A#5 | 10.20
4 |  | A5 | 11.00
5 |  | G5 | 12.00
6 |  | F5 | 13.00
7 |  | E5 | 13.80
8 |  | D5 | 15.00
9 |  | C5 | 16.20
10 |  | A#4 | 17.50
11 |  | A4 | 18.50
12 |  | G4 | 19.80
13 |  | F4 | 21.20
14 |  | E4 | 22.50
15 |  | D4 | 24.00
16 |  | C4 | 25.50
17 |  | A#3 | 27.00
18 |  | A3 | 28.20
19 |  | G3 | 29.50
20 |  | F3 | 30.50
21 |  | F3 | 31.10
(spare)
(spare)
(spare)
Actual string count: |  | Record the real count - decorative koras vary.

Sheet: Photo Log
Photo Log - document condition & geometry before disassembly
# | Shot | Purpose | Done | Filename | Notes
OVERALL
 | Front (soundboard) full, against a ruler/grid | Scale reference for the whole instrument
 | Back of gourd full | Shell shape, finish, cracks
 | Left side profile | Neck angle, bridge lean, proportions
 | Right side profile | Symmetry check
 | Top / head-on down the neck | Tuning-ring layout
DETAIL
 | Bridge straight-on (string-bank face) | Count + number notches, spacing
 | Bridge from side | Height, lean, foot, any pad
 | Bridge foot on skin | Footprint, contact, skin denting
 | Tuning rings close-up | Ring style, spacing, wear
 | String anchor / tail | Anchor type and how strings tie off
 | Handle posts (each) | Mounting, length, condition
 | Crossbars where they exit gourd | Diameter, fit, any splitting
 | Tack line close-up with ruler | Spacing, count, head size
 | Skin wrap-over at rim (edge) | Wrap depth, hide thickness, attach method
 | Sound hole / port if present | Size and position
CONDITION
 | Any cracks / repairs in gourd | Map damage before work
 | Skin tears, stains, looseness | Condition baseline for re-skin
 | Neck splits or loose joint | Structural check
 | Label / maker marks / stickers | Provenance
TRACINGS
 | Trace gourd rim outline on paper | New skin blank + rim reference
 | Trace bridge footprint | Rebuild reference
 | Trace/rubbing of tack pattern | Re-tack reference

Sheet: Condition & Restoration Log
Condition & Restoration Log
Area | Component | Condition found | Planned action | Materials needed | Done | Notes
Soundboard | Cowhide skin |  | Remove, save as template; install new cowskin | New rawhide/cowhide, water for soaking
Rim | Tacks |  | Remove + count; re-tack new skin | Brass/steel tacks to match
Bridge | Notched bridge |  | Clean / re-notch / replace; reseat | Hardwood blank if replacing
Bridge | Foot / pad |  | Inspect; add pad to spread load if needed | Leather/felt
Strings | All strings |  | Replace full set | Nylon / fishing line gauges per schedule
Anchor | String anchor / tail |  | Replace / rebuild | New anchor material
Neck | Neck shaft |  | Sand, then finish | Sandpaper grits, finish
Tuning | Leather rings |  | Inspect; replace/re-wrap as needed | Leather thong / cord
Handles | Hand posts (x2) |  | Sand, then finish | Sandpaper, finish
Crossbars | Side bars |  | Sand, then finish | Sandpaper, finish
Gourd | Calabash shell |  | Sand lightly; finish; stabilize cracks | Sandpaper, finish, adhesive if cracked
Finish | Whole instrument |  | Apply finish (test on hidden spot first) | Oil / shellac / wax - choose

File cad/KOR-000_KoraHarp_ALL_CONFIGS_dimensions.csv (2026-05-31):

AssemblyConfigName | Component | ConfigName | FeatureName | FeatureType | DimFullName | Value_mm | Value_in | Tolerance_Type | IsDriven | IsLinked | IsGlobalVar | EquationOrComment
Default | KOR-000_MasterLayout-1 | Default | Side Profile | ProfileFeature | D2@Side Profile@KOR-000_MasterLayout.Part | 533.4000 | 21.0000 | N/A | TRUE | FALSE | FALSE
Default | KOR-000_MasterLayout-1 | Default | Side Profile | ProfileFeature | D3@Side Profile@KOR-000_MasterLayout.Part | 50.8000 | 2.0000 | N/A | TRUE | FALSE | FALSE
Default | KOR-000_MasterLayout-1 | Default | Side Profile | ProfileFeature | D4@Side Profile@KOR-000_MasterLayout.Part | 293.3700 | 11.5500 | N/A | TRUE | FALSE | FALSE
Default | KOR-000_MasterLayout-1 | Default | Side Profile | ProfileFeature | D5@Side Profile@KOR-000_MasterLayout.Part | 17.4533 | 0.6871 | N/A | TRUE | FALSE | FALSE
Default | KOR-000_MasterLayout-1 | Default | Side Profile | ProfileFeature | D7@Side Profile@KOR-000_MasterLayout.Part | 44.4500 | 1.7500 | N/A | TRUE | FALSE | FALSE
Default | KOR-000_MasterLayout-1 | Default | Side Profile | ProfileFeature | D6@Side Profile@KOR-000_MasterLayout.Part | 38.1000 | 1.5000 | N/A | TRUE | FALSE | FALSE
Default | KOR-000_MasterLayout-1 | Default | Side Profile | ProfileFeature | D8@Side Profile@KOR-000_MasterLayout.Part | 19.0500 | 0.7500 | N/A | TRUE | FALSE | FALSE
Default | KOR-000_MasterLayout-1 | Default | Side Profile | ProfileFeature | D9@Side Profile@KOR-000_MasterLayout.Part | 152.4000 | 6.0000 | N/A | TRUE | FALSE | FALSE
Default | KOR-000_MasterLayout-1 | Default | Side Profile | ProfileFeature | D10@Side Profile@KOR-000_MasterLayout.Part | 7.9375 | 0.3125 | N/A | TRUE | FALSE | FALSE
Default | KOR-000_MasterLayout-1 | Default | Side Profile | ProfileFeature | D11@Side Profile@KOR-000_MasterLayout.Part | 6.9850 | 0.2750 | N/A | TRUE | FALSE | FALSE
Default | KOR-000_MasterLayout-1 | Default | Side Profile | ProfileFeature | D12@Side Profile@KOR-000_MasterLayout.Part | 101.6000 | 4.0000 | N/A | TRUE | FALSE | FALSE
Default | KOR-000_MasterLayout-1 | Default | Side Profile | ProfileFeature | D13@Side Profile@KOR-000_MasterLayout.Part | 1.5240 | 0.0600 | N/A | TRUE | FALSE | FALSE
Default | KOR-000_MasterLayout-1 | Default | Side Profile | ProfileFeature | D14@Side Profile@KOR-000_MasterLayout.Part | 1239.5200 | 48.8000 | N/A | TRUE | FALSE | FALSE
Default | KOR-000_MasterLayout-1 | Default | Side Profile | ProfileFeature | D15@Side Profile@KOR-000_MasterLayout.Part | 1.5240 | 0.0600 | N/A | TRUE | FALSE | FALSE
Default | KOR-000_MasterLayout-1 | Default | Side Profile | ProfileFeature | D16@Side Profile@KOR-000_MasterLayout.Part | 15.8750 | 0.6250 | N/A | TRUE | FALSE | FALSE
Default | KOR-000_MasterLayout-1 | Default | Side Profile | ProfileFeature | D17@Side Profile@KOR-000_MasterLayout.Part | 25.4000 | 1.0000 | N/A | FALSE | FALSE | FALSE
Default | KOR-000_MasterLayout-1 | Default | Side Profile | ProfileFeature | D18@Side Profile@KOR-000_MasterLayout.Part | 25.4000 | 1.0000 | N/A | FALSE | FALSE | FALSE
Default | KOR-000_MasterLayout-1 | Default | Side Profile | ProfileFeature | D19@Side Profile@KOR-000_MasterLayout.Part | 9.5250 | 0.3750 | N/A | TRUE | FALSE | FALSE
Default | KOR-000_MasterLayout-1 | Default | Side Profile | ProfileFeature | D20@Side Profile@KOR-000_MasterLayout.Part | 76.2000 | 3.0000 | N/A | TRUE | FALSE | FALSE
Default | KOR-000_MasterLayout-1 | Default | Side Profile | ProfileFeature | D22@Side Profile@KOR-000_MasterLayout.Part | 38.1000 | 1.5000 | N/A | FALSE | FALSE | FALSE
Default | KOR-000_MasterLayout-1 | Default | Side Profile | ProfileFeature | D21@Side Profile@KOR-000_MasterLayout.Part | 31.7500 | 1.2500 | N/A | FALSE | FALSE | FALSE
Default | KOR-000_MasterLayout-1 | Default | Side Profile | ProfileFeature | D23@Side Profile@KOR-000_MasterLayout.Part | 1016.0000 | 40.0000 | N/A | TRUE | FALSE | FALSE
Default | KOR-000_MasterLayout-1 | Default | Handle Mid Plane | RefPlane | D1@Handle Mid Plane@KOR-000_MasterLayout.Part | 9.5250 | 0.3750 | N/A | FALSE | FALSE | FALSE
Default | KOR-000_MasterLayout-1 | Default | Port_XZ_Angle | ProfileFeature | D2@Port_XZ_Angle@KOR-000_MasterLayout.Part | 293.3700 | 11.5500 | N/A | TRUE | FALSE | FALSE
Default | KOR-000_MasterLayout-1 | Default | Port_XZ_Angle | ProfileFeature | D1@Port_XZ_Angle@KOR-000_MasterLayout.Part | 1047.1976 | 41.2283 | N/A | FALSE | FALSE | FALSE
Default | KOR-000_MasterLayout-1 | Default | Port_YZ_Angle | ProfileFeature | D1@Port_YZ_Angle@KOR-000_MasterLayout.Part | 523.5988 | 20.6141 | N/A | FALSE | FALSE | FALSE
Default | KOR-000_MasterLayout-1 | Default | Port_YZ_Angle | ProfileFeature | D2@Port_YZ_Angle@KOR-000_MasterLayout.Part | 293.3700 | 11.5500 | N/A | TRUE | FALSE | FALSE
Default | KOR-000_MasterLayout-1 | Default | Eyebolt_Mid_Plane | ProfileFeature | D1@Eyebolt_Mid_Plane@KOR-000_MasterLayout.Part | 9.5250 | 0.3750 | N/A | FALSE | FALSE | FALSE
Default | KOR-000_MasterLayout-1 | Default | Eyebolt_Mid_Plane | ProfileFeature | D2@Eyebolt_Mid_Plane@KOR-000_MasterLayout.Part | 38.1000 | 1.5000 | N/A | FALSE | FALSE | FALSE
Default | KOR-000_MasterLayout-1 | Default | Eyebolt_Mid_Plane | ProfileFeature | D3@Eyebolt_Mid_Plane@KOR-000_MasterLayout.Part | 4.7625 | 0.1875 | N/A | FALSE | FALSE | FALSE
Default | KOR-000_MasterLayout-1 | Default | Eyebolt_Mid_Plane | ProfileFeature | D4@Eyebolt_Mid_Plane@KOR-000_MasterLayout.Part | 0.5080 | 0.0200 | N/A | FALSE | FALSE | FALSE
Default | KOR-000_MasterLayout-1 | Default | Eyebolt_Mid_Plane | ProfileFeature | D6@Eyebolt_Mid_Plane@KOR-000_MasterLayout.Part | 139.6263 | 5.4971 | N/A | FALSE | FALSE | FALSE
Default | KOR-000_MasterLayout-1 | Default | Eyebolt_Mid_Plane | ProfileFeature | D5@Eyebolt_Mid_Plane@KOR-000_MasterLayout.Part | 11000.0000 | 433.0709 | N/A | FALSE | FALSE | FALSE
Default | KOR-000_MasterLayout-1 | Default | Eyebolt_Mid_Plane | ProfileFeature | D8@Eyebolt_Mid_Plane@KOR-000_MasterLayout.Part | 139.6263 | 5.4971 | N/A | FALSE | FALSE | FALSE
Default | KOR-000_MasterLayout-1 | Default | Eyebolt_Mid_Plane | ProfileFeature | D7@Eyebolt_Mid_Plane@KOR-000_MasterLayout.Part | 11000.0000 | 433.0709 | N/A | FALSE | FALSE | FALSE
Default | KOR-000_MasterLayout-1 | Default | Bridge_String_Holes | ProfileFeature | D1@Bridge_String_Holes@KOR-000_MasterLayout.Part | 63.5000 | 2.5000 | N/A | TRUE | FALSE | FALSE
Default | KOR-000_MasterLayout-1 | Default | Bridge_String_Holes | ProfileFeature | D2@Bridge_String_Holes@KOR-000_MasterLayout.Part | 4.3180 | 0.1700 | N/A | FALSE | FALSE | FALSE
Default | KOR-000_MasterLayout-1 | Default | Bridge_String_Holes | ProfileFeature | D3@Bridge_String_Holes@KOR-000_MasterLayout.Part | 25.4000 | 1.0000 | N/A | FALSE | FALSE | FALSE
Default | KOR-000_MasterLayout-1 | Default | Bridge_String_Holes | ProfileFeature | D4@Bridge_String_Holes@KOR-000_MasterLayout.Part | 9.5250 | 0.3750 | N/A | FALSE | FALSE | FALSE
Default | KOR-000_MasterLayout-1 | Default | Bridge_String_Holes | ProfileFeature | D5@Bridge_String_Holes@KOR-000_MasterLayout.Part | 25.0288 | 0.9854 | N/A | FALSE | FALSE | FALSE
Default | KOR-000_MasterLayout-1 | Default | Bridge_String_Holes | ProfileFeature | D6@Bridge_String_Holes@KOR-000_MasterLayout.Part | 9.5250 | 0.3750 | N/A | FALSE | FALSE | FALSE
Default | KOR-000_MasterLayout-1 | Default | Bridge_String_Holes | ProfileFeature | D7@Bridge_String_Holes@KOR-000_MasterLayout.Part | 11000.0000 | 433.0709 | N/A | FALSE | FALSE | FALSE
Default | KOR-000_MasterLayout-1 | Default | Bridge_String_Holes | ProfileFeature | D8@Bridge_String_Holes@KOR-000_MasterLayout.Part | 12.7000 | 0.5000 | N/A | FALSE | FALSE | FALSE
Default | KOR-000_MasterLayout-1 | Default | Sound_Hole | ProfileFeature | D1@Sound_Hole@KOR-000_MasterLayout.Part | 79.2480 | 3.1200 | N/A | FALSE | FALSE | FALSE
Default | KOR-000_MasterLayout-1 | Default | Sound_Hole | ProfileFeature | D2@Sound_Hole@KOR-000_MasterLayout.Part | 127.0000 | 5.0000 | N/A | FALSE | FALSE | FALSE
Default | KOR-000_MasterLayout-1 | Default | Neck Face | ProfileFeature | D1@Neck Face@KOR-000_MasterLayout.Part | 44.4500 | 1.7500 | N/A | TRUE | FALSE | FALSE
Default | KOR-000_MasterLayout-1 | Default | Neck Face | ProfileFeature | D2@Neck Face@KOR-000_MasterLayout.Part | 77.9780 | 3.0700 | N/A | TRUE | FALSE | FALSE
Default | KOR-000_MasterLayout-1 | Default | Neck Face | ProfileFeature | D3@Neck Face@KOR-000_MasterLayout.Part | 160.0200 | 6.3000 | N/A | TRUE | FALSE | FALSE
Default | KOR-000_MasterLayout-1 | Default | Neck Face | ProfileFeature | D4@Neck Face@KOR-000_MasterLayout.Part | 16.5100 | 0.6500 | N/A | FALSE | FALSE | FALSE
Default | KOR-000_MasterLayout-1 | Default | Neck Face | ProfileFeature | D5@Neck Face@KOR-000_MasterLayout.Part | 16.5100 | 0.6500 | N/A | FALSE | FALSE | FALSE
Default | KOR-000_MasterLayout-1 | Default | Neck Face | ProfileFeature | D6@Neck Face@KOR-000_MasterLayout.Part | 39.8780 | 1.5700 | N/A | TRUE | FALSE | FALSE
Default | KOR-000_MasterLayout-1 | Default | Neck Face | ProfileFeature | D7@Neck Face@KOR-000_MasterLayout.Part | 123.9520 | 4.8800 | N/A | TRUE | FALSE | FALSE
Default | KOR-000_MasterLayout-1 | Default | Neck Face | ProfileFeature | D8@Neck Face@KOR-000_MasterLayout.Part | 200.9140 | 7.9100 | N/A | TRUE | FALSE | FALSE
Default | KOR-000_MasterLayout-1 | Default | Neck Face | ProfileFeature | D9@Neck Face@KOR-000_MasterLayout.Part | 243.0780 | 9.5700 | N/A | TRUE | FALSE | FALSE
Default | KOR-000_MasterLayout-1 | Default | Neck Face | ProfileFeature | D10@Neck Face@KOR-000_MasterLayout.Part | 278.8920 | 10.9800 | N/A | TRUE | FALSE | FALSE
Default | KOR-000_MasterLayout-1 | Default | Neck Face | ProfileFeature | D11@Neck Face@KOR-000_MasterLayout.Part | 314.9600 | 12.4000 | N/A | TRUE | FALSE | FALSE
Default | KOR-000_MasterLayout-1 | Default | Neck Face | ProfileFeature | D12@Neck Face@KOR-000_MasterLayout.Part | 349.7580 | 13.7700 | N/A | TRUE | FALSE | FALSE
Default | KOR-000_MasterLayout-1 | Default | Neck Face | ProfileFeature | D13@Neck Face@KOR-000_MasterLayout.Part | 383.7940 | 15.1100 | N/A | TRUE | FALSE | FALSE
Default | KOR-000_MasterLayout-1 | Default | Neck Face | ProfileFeature | D14@Neck Face@KOR-000_MasterLayout.Part | 416.5600 | 16.4000 | N/A | TRUE | FALSE | FALSE
Default | KOR-000_MasterLayout-1 | Default | Neck Face | ProfileFeature | D15@Neck Face@KOR-000_MasterLayout.Part | 447.0400 | 17.6000 | N/A | TRUE | FALSE | FALSE
Default | KOR-000_MasterLayout-1 | Default | Neck Face | ProfileFeature | D16@Neck Face@KOR-000_MasterLayout.Part | 478.7900 | 18.8500 | N/A | TRUE | FALSE | FALSE
Default | KOR-000_MasterLayout-1 | Default | Neck Face | ProfileFeature | D17@Neck Face@KOR-000_MasterLayout.Part | 508.0000 | 20.0000 | N/A | TRUE | FALSE | FALSE
Default | KOR-000_MasterLayout-1 | Default | Neck Face | ProfileFeature | D18@Neck Face@KOR-000_MasterLayout.Part | 536.9560 | 21.1400 | N/A | TRUE | FALSE | FALSE
Default | KOR-000_MasterLayout-1 | Default | Neck Face | ProfileFeature | D19@Neck Face@KOR-000_MasterLayout.Part | 563.8800 | 22.2000 | N/A | TRUE | FALSE | FALSE
Default | KOR-000_MasterLayout-1 | Default | Neck Face | ProfileFeature | D20@Neck Face@KOR-000_MasterLayout.Part | 591.8200 | 23.3000 | N/A | TRUE | FALSE | FALSE
Default | KOR-000_MasterLayout-1 | Default | Neck Face | ProfileFeature | D21@Neck Face@KOR-000_MasterLayout.Part | 614.9340 | 24.2100 | N/A | TRUE | FALSE | FALSE
Default | KOR-000_MasterLayout-1 | Default | Neck Face | ProfileFeature | D22@Neck Face@KOR-000_MasterLayout.Part | 642.8740 | 25.3100 | N/A | TRUE | FALSE | FALSE
Default | KOR-000_MasterLayout-1 | Default | Neck Face | ProfileFeature | D23@Neck Face@KOR-000_MasterLayout.Part | 663.9560 | 26.1400 | N/A | TRUE | FALSE | FALSE
Default | KOR-000_MasterLayout-1 | Default | Neck Face | ProfileFeature | D24@Neck Face@KOR-000_MasterLayout.Part | 689.8640 | 27.1600 | N/A | TRUE | FALSE | FALSE
Default | KOR-000_MasterLayout-1 | Default | Neck Face | ProfileFeature | D25@Neck Face@KOR-000_MasterLayout.Part | 6.3500 | 0.2500 | N/A | FALSE | FALSE | FALSE
Default | KOR-000_MasterLayout-1 | Default | Neck_Slot | ProfileFeature | D1@Neck_Slot@KOR-000_MasterLayout.Part | 16.9926 | 0.6690 | N/A | TRUE | FALSE | FALSE
Default | KOR-000_MasterLayout-1 | Default | Neck_Slot | ProfileFeature | D2@Neck_Slot@KOR-000_MasterLayout.Part | 15.0114 | 0.5910 | N/A | TRUE | FALSE | FALSE
Default | KOR-000_MasterLayout-1 | Default | Left_Handle | ProfileFeature | D1@Handle Mid Plane@KOR-000_MasterLayout.Part | 9.5250 | 0.3750 | N/A | FALSE | FALSE | FALSE
Default | KOR-000_MasterLayout-1 | Default | Left_Handle | ProfileFeature | D1@Left_Handle@KOR-000_MasterLayout.Part | 660.4000 | 26.0000 | N/A | FALSE | FALSE | FALSE
Default | KOR-000_MasterLayout-1 | Default | Left_Handle | ProfileFeature | D2@Left_Handle@KOR-000_MasterLayout.Part | 19.0500 | 0.7500 | N/A | FALSE | FALSE | FALSE
Default | KOR-000_MasterLayout-1 | Default | Left_Handle | ProfileFeature | D3@Left_Handle@KOR-000_MasterLayout.Part | 31.7500 | 1.2500 | N/A | FALSE | FALSE | FALSE
Default | KOR-000_MasterLayout-1 | Default | Left_Handle | ProfileFeature | D5@Left_Handle@KOR-000_MasterLayout.Part | 34.9066 | 1.3743 | N/A | TRUE | FALSE | FALSE
Default | KOR-000_MasterLayout-1 | Default | Left_Handle | ProfileFeature | D6@Left_Handle@KOR-000_MasterLayout.Part | 139.7000 | 5.5000 | N/A | TRUE | FALSE | FALSE
Default | KOR-000_MasterLayout-1 | Default | Left_Handle | ProfileFeature | D4@Left_Handle@KOR-000_MasterLayout.Part | 129.5400 | 5.1000 | N/A | TRUE | FALSE | FALSE
Default | KOR-000_MasterLayout-1 | Default | Left_Handle | ProfileFeature | D7@Left_Handle@KOR-000_MasterLayout.Part | 129.5400 | 5.1000 | N/A | TRUE | FALSE | FALSE
Default | KOR-000_MasterLayout-1 | Default | 3DSketch1 | 3DProfileFeature | D1@3DSketch1@KOR-000_MasterLayout.Part | 1217.8299 | 47.9461 | N/A | TRUE | FALSE | FALSE
Default | KOR-000_MasterLayout-1 | Default | 3DSketch1 | 3DProfileFeature | D2@3DSketch1@KOR-000_MasterLayout.Part | 1132.5953 | 44.5904 | N/A | TRUE | FALSE | FALSE
Default | KOR-000_MasterLayout-1 | Default | 3DSketch1 | 3DProfileFeature | D3@3DSketch1@KOR-000_MasterLayout.Part | 1054.3904 | 41.5114 | N/A | TRUE | FALSE | FALSE
Default | KOR-000_MasterLayout-1 | Default | 3DSketch1 | 3DProfileFeature | D4@3DSketch1@KOR-000_MasterLayout.Part | 975.1839 | 38.3931 | N/A | TRUE | FALSE | FALSE
Default | KOR-000_MasterLayout-1 | Default | 3DSketch1 | 3DProfileFeature | D5@3DSketch1@KOR-000_MasterLayout.Part | 903.0106 | 35.5516 | N/A | TRUE | FALSE | FALSE
Default | KOR-000_MasterLayout-1 | Default | 3DSketch1 | 3DProfileFeature | D6@3DSketch1@KOR-000_MasterLayout.Part | 1180.2001 | 46.4646 | N/A | TRUE | FALSE | FALSE
Default | KOR-000_MasterLayout-1 | Default | 3DSketch1 | 3DProfileFeature | D7@3DSketch1@KOR-000_MasterLayout.Part | 1012.7504 | 39.8721 | N/A | TRUE | FALSE | FALSE
Default | KOR-000_MasterLayout-1 | Default | 3DSketch1 | 3DProfileFeature | D8@3DSketch1@KOR-000_MasterLayout.Part | 939.5616 | 36.9906 | N/A | TRUE | FALSE | FALSE
Default | KOR-000_MasterLayout-1 | Default | 3DSketch1 | 3DProfileFeature | D9@3DSketch1@KOR-000_MasterLayout.Part | 869.3871 | 34.2278 | N/A | TRUE | FALSE | FALSE
Default | KOR-000_MasterLayout-1 | Default | 3DSketch1 | 3DProfileFeature | D10@3DSketch1@KOR-000_MasterLayout.Part | 804.7406 | 31.6827 | N/A | TRUE | FALSE | FALSE
Default | KOR-000_MasterLayout-1 | Default | 3DSketch1 | 3DProfileFeature | D11@3DSketch1@KOR-000_MasterLayout.Part | 742.3682 | 29.2271 | N/A | TRUE | FALSE | FALSE
Default | KOR-000_MasterLayout-1 | Default | 3DSketch1 | 3DProfileFeature | D12@3DSketch1@KOR-000_MasterLayout.Part | 685.0431 | 26.9702 | N/A | TRUE | FALSE | FALSE
Default | KOR-000_MasterLayout-1 | Default | 3DSketch1 | 3DProfileFeature | D13@3DSketch1@KOR-000_MasterLayout.Part | 632.5344 | 24.9029 | N/A | TRUE | FALSE | FALSE
Default | KOR-000_MasterLayout-1 | Default | 3DSketch1 | 3DProfileFeature | D14@3DSketch1@KOR-000_MasterLayout.Part | 582.0986 | 22.9173 | N/A | TRUE | FALSE | FALSE
Default | KOR-000_MasterLayout-1 | Default | 3DSketch1 | 3DProfileFeature | D15@3DSketch1@KOR-000_MasterLayout.Part | 554.6935 | 21.8383 | N/A | TRUE | FALSE | FALSE
Default | KOR-000_MasterLayout-1 | Default | 3DSketch1 | 3DProfileFeature | D16@3DSketch1@KOR-000_MasterLayout.Part | 1096.9757 | 43.1880 | N/A | TRUE | FALSE | FALSE
Default | KOR-000_MasterLayout-1 | Default | 3DSketch1 | 3DProfileFeature | D17@3DSketch1@KOR-000_MasterLayout.Part | 834.8633 | 32.8686 | N/A | TRUE | FALSE | FALSE
Default | KOR-000_MasterLayout-1 | Default | 3DSketch1 | 3DProfileFeature | D18@3DSketch1@KOR-000_MasterLayout.Part | 771.2521 | 30.3643 | N/A | TRUE | FALSE | FALSE
Default | KOR-000_MasterLayout-1 | Default | 3DSketch1 | 3DProfileFeature | D19@3DSketch1@KOR-000_MasterLayout.Part | 711.6869 | 28.0192 | N/A | TRUE | FALSE | FALSE
Default | KOR-000_MasterLayout-1 | Default | 3DSketch1 | 3DProfileFeature | D20@3DSketch1@KOR-000_MasterLayout.Part | 655.4291 | 25.8043 | N/A | TRUE | FALSE | FALSE
Default | KOR-000_MasterLayout-1 | Default | 3DSketch1 | 3DProfileFeature | D21@3DSketch1@KOR-000_MasterLayout.Part | 603.0038 | 23.7403 | N/A | TRUE | FALSE | FALSE
Default | KOR-000_MasterLayout-1 | Default | [Equation 0] | Equation |  |  |  |  |  |  | TRUE | "bowl_diameter_in"= 21in
Default | KOR-000_MasterLayout-1 | Default | [Equation 1] | Equation |  |  |  |  |  |  | TRUE | "neck_length_in"= 40in
Default | KOR-000_MasterLayout-1 | Default | [Equation 2] | Equation |  |  |  |  |  |  | TRUE | "bridge_height_in"= 6.0in
Default | KOR-000_MasterLayout-1 | Default | [Equation 3] | Equation |  |  |  |  |  |  | TRUE | "bridge_width_in"= 2.5in
Default | KOR-000_MasterLayout-1 | Default | [Equation 4] | Equation |  |  |  |  |  |  | TRUE | "bridge_thickness_in"= 0.75in
Default | KOR-000_MasterLayout-1 | Default | [Equation 5] | Equation |  |  |  |  |  |  | TRUE | "string_count"= 21
Default | KOR-000_MasterLayout-1 | Default | [Equation 6] | Equation |  |  |  |  |  |  | TRUE | "string_spacing_in"= "bridge_width_in" * 12 / ( "string_count" + 1 ) / 12
Default | KOR-000_MasterLayout-1 | Default | [Equation 7] | Equation |  |  |  |  |  |  | TRUE | "segments_per_ring"= 12
Default | KOR-000_MasterLayout-1 | Default | [Equation 8] | Equation |  |  |  |  |  |  | TRUE | "ring_height_in"= 0.75in
Default | KOR-000_MasterLayout-1 | Default | [Equation 9] | Equation |  |  |  |  |  |  | TRUE | "ring_count"= 14
Default | KOR-000_MasterLayout-1 | Default | [Equation 10] | Equation |  |  |  |  |  |  | TRUE | "rim_segments"= 16
Default | KOR-000_MasterLayout-1 | Default | [Equation 11] | Equation |  |  |  |  |  |  | TRUE | "rim_miter_deg"= 11.25
Default | KOR-000_MasterLayout-1 | Default | [Equation 12] | Equation |  |  |  |  |  |  | TRUE | "bowl_miter_deg"= 15
Default | KOR-000_MasterLayout-1 | Default | [Equation 13] | Equation |  |  |  |  |  |  | TRUE | "string_len_short_in"= 8.7in
Default | KOR-000_MasterLayout-1 | Default | [Equation 14] | Equation |  |  |  |  |  |  | TRUE | "string_len_long_in"= 31.1in
Default | KOR-000_MasterLayout-1 | Default | [Equation 15] | Equation |  |  |  |  |  |  | FALSE | "D2@Side Profile"="bowl_diameter_in"
Default | KOR-000_MasterLayout-1 | Default | [Equation 16] | Equation |  |  |  |  |  |  | TRUE | "foot_of_neck"= 2.0in
Default | KOR-000_MasterLayout-1 | Default | [Equation 17] | Equation |  |  |  |  |  |  | FALSE | "D3@Side Profile"="foot_of_neck"
Default | KOR-000_MasterLayout-1 | Default | [Equation 18] | Equation |  |  |  |  |  |  | TRUE | "neck_lean_back"= 1
Default | KOR-000_MasterLayout-1 | Default | [Equation 19] | Equation |  |  |  |  |  |  | FALSE | "D5@Side Profile"="neck_lean_back"
Default | KOR-000_MasterLayout-1 | Default | [Equation 20] | Equation |  |  |  |  |  |  | TRUE | "foot_to_anchor"= 1.25in
Default | KOR-000_MasterLayout-1 | Default | [Equation 21] | Equation |  |  |  |  |  |  | TRUE | "sphere-chord-factor"= 0.55
Default | KOR-000_MasterLayout-1 | Default | [Equation 22] | Equation |  |  |  |  |  |  | TRUE | "bowl_depth_in"= "bowl_diameter_in" * "sphere-chord-factor"
Default | KOR-000_MasterLayout-1 | Default | [Equation 23] | Equation |  |  |  |  |  |  | FALSE | "D4@Side Profile"="bowl_depth_in"
Default | KOR-000_MasterLayout-1 | Default | [Equation 24] | Equation |  |  |  |  |  |  | TRUE | "scale_factor"= "bowl_diameter_in" / 21in
Default | KOR-000_MasterLayout-1 | Default | [Equation 25] | Equation |  |  |  |  |  |  | TRUE | "gourd_wall_in"= 5 / 16in
Default | KOR-000_MasterLayout-1 | Default | [Equation 26] | Equation |  |  |  |  |  |  | TRUE | "sound_hole_w_in"= 175 * 25.4 * "scale_factor" / 1000
Default | KOR-000_MasterLayout-1 | Default | [Equation 27] | Equation |  |  |  |  |  |  | TRUE | "bridge_x_from_necktop"= 47.17 * "scale_factor"
Default | KOR-000_MasterLayout-1 | Default | [Equation 28] | Equation |  |  |  |  |  |  | TRUE | "hand_post_yz_in"= 5.1 * "scale_factor"
Default | KOR-000_MasterLayout-1 | Default | [Equation 29] | Equation |  |  |  |  |  |  | TRUE | "cross_brace_len_in"= 16.25 * "scale_factor"
Default | KOR-000_MasterLayout-1 | Default | [Equation 30] | Equation |  |  |  |  |  |  | TRUE | "tail_anchor_rs_in"= 3.0 * "scale_factor"
Default | KOR-000_MasterLayout-1 | Default | [Equation 31] | Equation |  |  |  |  |  |  | TRUE | "neck_width_in"= 1.75in
Default | KOR-000_MasterLayout-1 | Default | [Equation 32] | Equation |  |  |  |  |  |  | TRUE | "neck_height_in"= 1.75in
Default | KOR-000_MasterLayout-1 | Default | [Equation 33] | Equation |  |  |  |  |  |  | TRUE | "neck_slot_w_in"= .669in
Default | KOR-000_MasterLayout-1 | Default | [Equation 34] | Equation |  |  |  |  |  |  | TRUE | "neck_slot_d_in"= 0.591in
Default | KOR-000_MasterLayout-1 | Default | [Equation 35] | Equation |  |  |  |  |  |  | TRUE | "neck_wall_in"= .551in
Default | KOR-000_MasterLayout-1 | Default | [Equation 36] | Equation |  |  |  |  |  |  | TRUE | "neck_below_gourd_in"= 1.5in
Default | KOR-000_MasterLayout-1 | Default | [Equation 37] | Equation |  |  |  |  |  |  | TRUE | "hand_post_dia_in"= 0.75in
Default | KOR-000_MasterLayout-1 | Default | [Equation 38] | Equation |  |  |  |  |  |  | TRUE | "hand_post_len_in"= 26in
Default | KOR-000_MasterLayout-1 | Default | [Equation 39] | Equation |  |  |  |  |  |  | TRUE | "hand_post_ball_in"= 1.25in
Default | KOR-000_MasterLayout-1 | Default | [Equation 40] | Equation |  |  |  |  |  |  | TRUE | "cross_brace_dia_in"= 0.625in
Default | KOR-000_MasterLayout-1 | Default | [Equation 41] | Equation |  |  |  |  |  |  | TRUE | "tail_ring_od_in"= 3.0in
Default | KOR-000_MasterLayout-1 | Default | [Equation 42] | Equation |  |  |  |  |  |  | TRUE | "string_exits_ahead_in"= 10mm
Default | KOR-000_MasterLayout-1 | Default | [Equation 43] | Equation |  |  |  |  |  |  | TRUE | "bridge_pad_t_in"= .275in
Default | KOR-000_MasterLayout-1 | Default | [Equation 44] | Equation |  |  |  |  |  |  | TRUE | "bridge_thick_in"= 0.75in
Default | KOR-000_MasterLayout-1 | Default | [Equation 45] | Equation |  |  |  |  |  |  | TRUE | "holes_from_rim_in"= 1.0
Default | KOR-000_MasterLayout-1 | Default | [Equation 46] | Equation |  |  |  |  |  |  | FALSE | "D7@Side Profile"="neck_height_in"
Default | KOR-000_MasterLayout-1 | Default | [Equation 47] | Equation |  |  |  |  |  |  | FALSE | "D6@Side Profile"="neck_below_gourd_in"
Default | KOR-000_MasterLayout-1 | Default | [Equation 48] | Equation |  |  |  |  |  |  | FALSE | "D8@Side Profile"="bridge_thickness_in"
Default | KOR-000_MasterLayout-1 | Default | [Equation 49] | Equation |  |  |  |  |  |  | FALSE | "D9@Side Profile"="bridge_height_in"
Default | KOR-000_MasterLayout-1 | Default | [Equation 50] | Equation |  |  |  |  |  |  | FALSE | "D10@Side Profile"="gourd_wall_in"
Default | KOR-000_MasterLayout-1 | Default | [Equation 51] | Equation |  |  |  |  |  |  | TRUE | "hand_post_angle"= 2
Default | KOR-000_MasterLayout-1 | Default | [Equation 52] | Equation |  |  |  |  |  |  | FALSE | "D5@Left_Handle"="hand_post_angle"
Default | KOR-000_MasterLayout-1 | Default | [Equation 53] | Equation |  |  |  |  |  |  | TRUE | "handle_exposure"= 5.5in
Default | KOR-000_MasterLayout-1 | Default | [Equation 54] | Equation |  |  |  |  |  |  | FALSE | "D6@Left_Handle"="handle_exposure"
Default | KOR-000_MasterLayout-1 | Default | [Equation 55] | Equation |  |  |  |  |  |  | FALSE | "D1@Neck Face"="neck_width_in"
Default | KOR-000_MasterLayout-1 | Default | [Equation 56] | Equation |  |  |  |  |  |  | FALSE | "D2@Port_XZ_Angle"="bowl_depth_in"
Default | KOR-000_MasterLayout-1 | Default | [Equation 57] | Equation |  |  |  |  |  |  | FALSE | "D2@Port_YZ_Angle"="bowl_depth_in"
Default | KOR-000_MasterLayout-1 | Default | [Equation 58] | Equation |  |  |  |  |  |  | TRUE | "bridge_pad_w_in"= 2.0in
Default | KOR-000_MasterLayout-1 | Default | [Equation 59] | Equation |  |  |  |  |  |  | TRUE | "bridge_pad_l_in"= 4.0in
Default | KOR-000_MasterLayout-1 | Default | [Equation 60] | Equation |  |  |  |  |  |  | FALSE | "D11@Side Profile"="bridge_pad_t_in"
Default | KOR-000_MasterLayout-1 | Default | [Equation 61] | Equation |  |  |  |  |  |  | FALSE | "D12@Side Profile"="bridge_pad_l_in"
Default | KOR-000_MasterLayout-1 | Default | [Equation 62] | Equation |  |  |  |  |  |  | TRUE | "membrane_thickness"= 0.060in
Default | KOR-000_MasterLayout-1 | Default | [Equation 63] | Equation |  |  |  |  |  |  | FALSE | "D13@Side Profile"="membrane_thickness"
Default | KOR-000_MasterLayout-1 | Default | [Equation 64] | Equation |  |  |  |  |  |  | TRUE | "bridge_to_neck"= 48.8 * "scale_factor"
Default | KOR-000_MasterLayout-1 | Default | [Equation 65] | Equation |  |  |  |  |  |  | FALSE | "D14@Side Profile"="bridge_to_neck"
Default | KOR-000_MasterLayout-1 | Default | [Equation 66] | Equation |  |  |  |  |  |  | FALSE | "D15@Side Profile"="membrane_thickness"
Default | KOR-000_MasterLayout-1 | Default | [Equation 67] | Equation |  |  |  |  |  |  | FALSE | "D16@Side Profile"="cross_brace_dia_in"
Default | KOR-000_MasterLayout-1 | Default | [Equation 68] | Equation |  |  |  |  |  |  | FALSE | "D1@Bridge_String_Holes"="bridge_width_in"
Default | KOR-000_MasterLayout-1 | Default | [Equation 69] | Equation |  |  |  |  |  |  | TRUE | "anchor_width_in"= 0.375in
Default | KOR-000_MasterLayout-1 | Default | [Equation 70] | Equation |  |  |  |  |  |  | TRUE | "anchor_len_in"= 3in
Default | KOR-000_MasterLayout-1 | Default | [Equation 71] | Equation |  |  |  |  |  |  | FALSE | "D19@Side Profile"="anchor_width_in"
Default | KOR-000_MasterLayout-1 | Default | [Equation 72] | Equation |  |  |  |  |  |  | FALSE | "D20@Side Profile"="anchor_len_in"
Default | KOR-000_MasterLayout-1 | Default | [Equation 73] | Equation |  |  |  |  |  |  | FALSE | "D1@Neck_Slot"="neck_slot_w_in"
Default | KOR-000_MasterLayout-1 | Default | [Equation 74] | Equation |  |  |  |  |  |  | FALSE | "D2@Neck_Slot"="neck_slot_d_in"
Default | KOR-000_MasterLayout-1 | Default | [Equation 75] | Equation |  |  |  |  |  |  | TRUE | "s1_neck"= 1.57in * "scale_factor"
Default | KOR-000_MasterLayout-1 | Default | [Equation 76] | Equation |  |  |  |  |  |  | TRUE | "s2_neck"= 3.07in * "scale_factor"
Default | KOR-000_MasterLayout-1 | Default | [Equation 77] | Equation |  |  |  |  |  |  | TRUE | "s3_neck"= 4.88in * "scale_factor"
Default | KOR-000_MasterLayout-1 | Default | [Equation 78] | Equation |  |  |  |  |  |  | TRUE | "s4_neck"= 6.30in * "scale_factor"
Default | KOR-000_MasterLayout-1 | Default | [Equation 79] | Equation |  |  |  |  |  |  | TRUE | "s5_neck"= 7.91in * "scale_factor"
Default | KOR-000_MasterLayout-1 | Default | [Equation 80] | Equation |  |  |  |  |  |  | TRUE | "s6_neck"= 9.57in * "scale_factor"
Default | KOR-000_MasterLayout-1 | Default | [Equation 81] | Equation |  |  |  |  |  |  | TRUE | "s7_neck"= 10.98in * "scale_factor"
Default | KOR-000_MasterLayout-1 | Default | [Equation 82] | Equation |  |  |  |  |  |  | TRUE | "s8_neck"= 12.40in * "scale_factor"
Default | KOR-000_MasterLayout-1 | Default | [Equation 83] | Equation |  |  |  |  |  |  | TRUE | "s9_neck"= 13.77in * "scale_factor"
Default | KOR-000_MasterLayout-1 | Default | [Equation 84] | Equation |  |  |  |  |  |  | TRUE | "s10_neck"= 15.11in * "scale_factor"
Default | KOR-000_MasterLayout-1 | Default | [Equation 85] | Equation |  |  |  |  |  |  | TRUE | "s11_neck"= 16.4in * "scale_factor"
Default | KOR-000_MasterLayout-1 | Default | [Equation 86] | Equation |  |  |  |  |  |  | TRUE | "s12_neck"= 17.6in * "scale_factor"
Default | KOR-000_MasterLayout-1 | Default | [Equation 87] | Equation |  |  |  |  |  |  | TRUE | "s13_neck"= 18.85in * "scale_factor"
Default | KOR-000_MasterLayout-1 | Default | [Equation 88] | Equation |  |  |  |  |  |  | TRUE | "s14_neck"= 20in * "scale_factor"
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

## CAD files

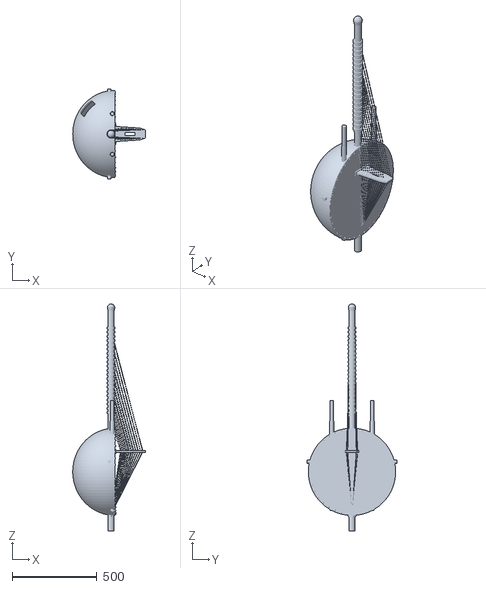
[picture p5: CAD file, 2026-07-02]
arena/round1/kora-arena-winner.stl
428.8 x 530.0 x 1341.8

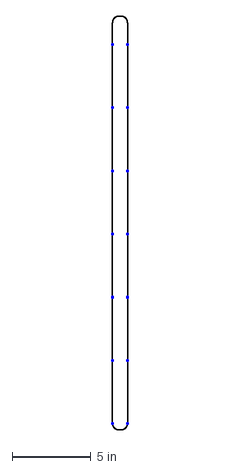
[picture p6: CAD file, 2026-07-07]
cad-recovered-2026-07-04/cad/neck_cnc/KOR-NECK-Cover.dxf
1.06 x 26.2 in

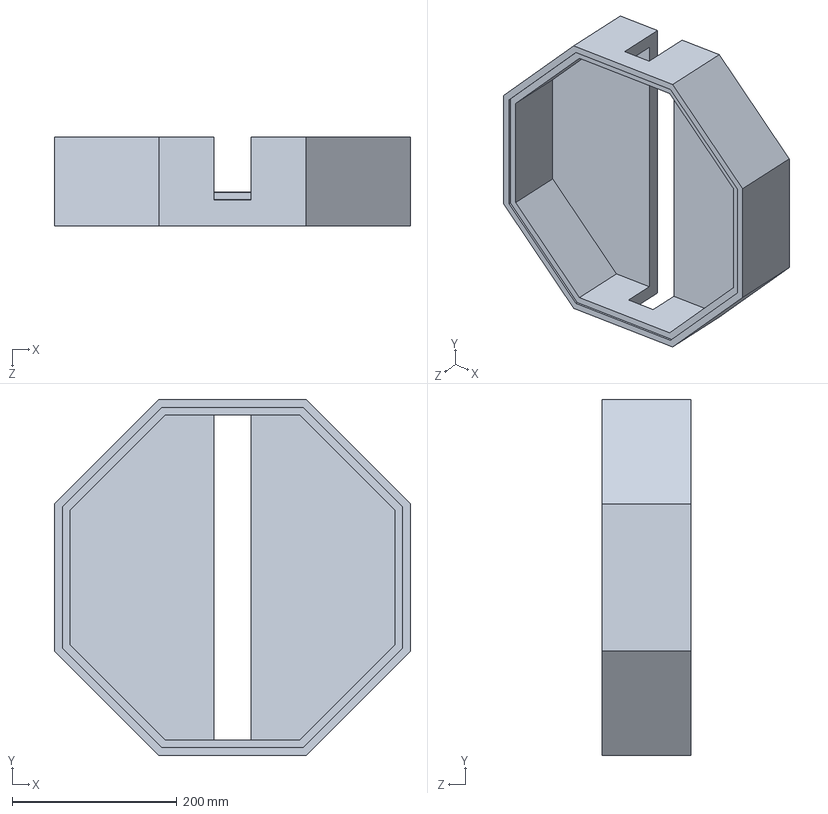
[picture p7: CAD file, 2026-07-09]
cad/Travel Kora Body.SLDPRT
431.8 x 431.8 x 108.0 mm

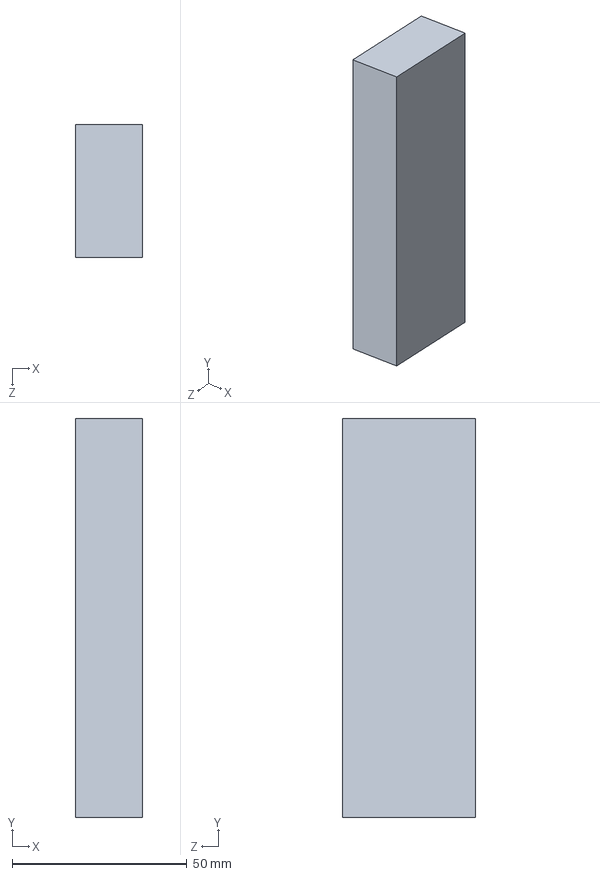
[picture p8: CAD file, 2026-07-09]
cad-recovered-2026-07-04/cad/KOR-000-LaminateTop.SLDPRT
19.1 x 114.3 x 38.1 mm

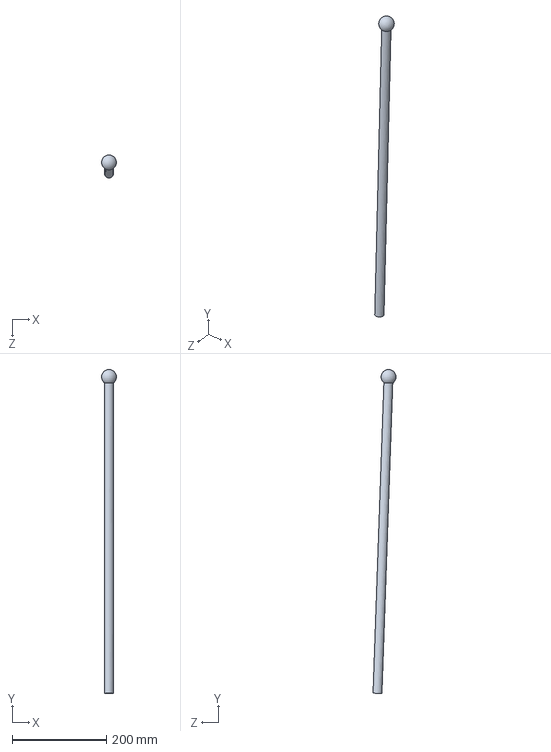
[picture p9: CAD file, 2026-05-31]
cad-recovered-from-stash-20260518/cad/KOR-000-Handle.SLDPRT
31.6 x 688.9 x 48.9 mm

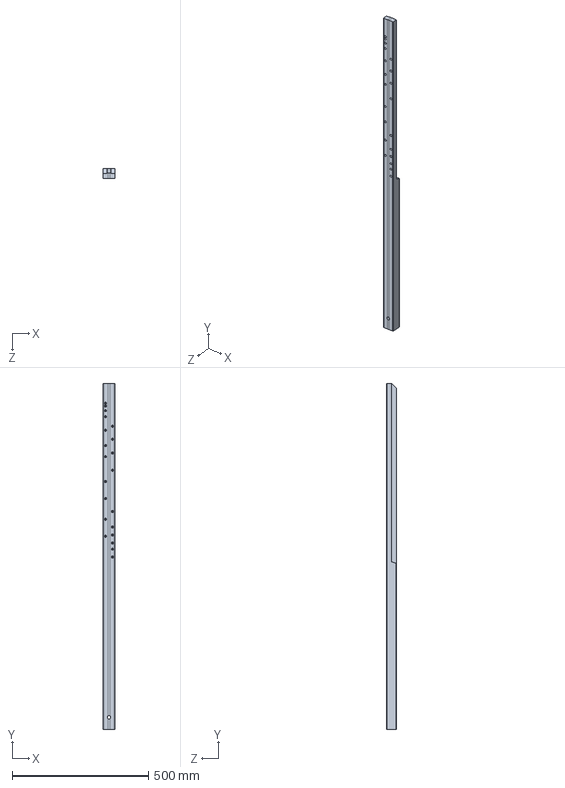
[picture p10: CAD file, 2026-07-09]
cad/neck2_cnc/KOR-NECK-GlueUp.SLDPRT
44.5 x 1270.0 x 38.1 mm

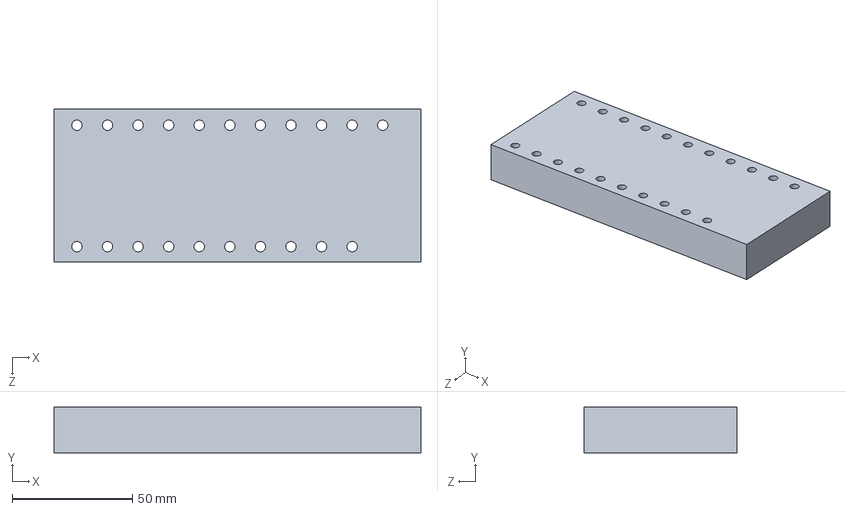
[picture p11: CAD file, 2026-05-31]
cad-recovered-from-stash-20260518/cad/KOR-000-Bridge.SLDPRT
152.4 x 19.1 x 63.5 mm

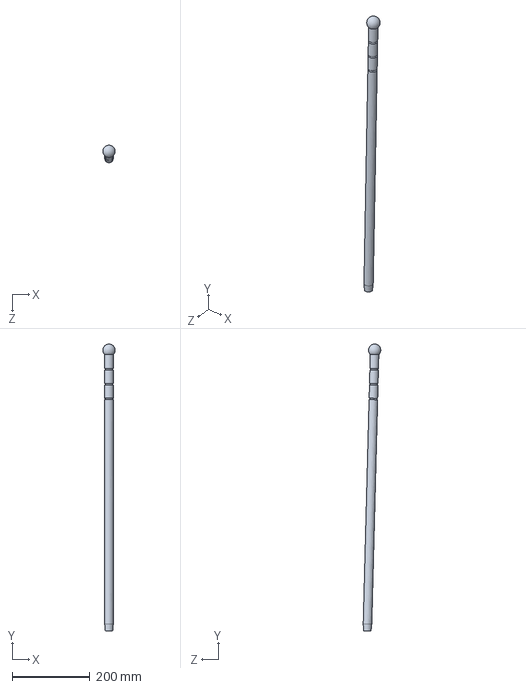
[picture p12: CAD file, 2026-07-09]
cad/KOR-000-Handle.SLDPRT
31.7 x 738.4 x 45.4 mm

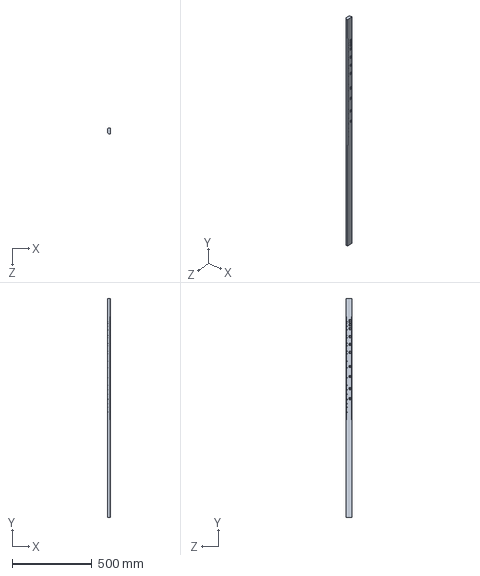
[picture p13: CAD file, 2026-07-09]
cad-recovered-2026-07-04/cad/KOR-000-LaminateNeckMirror.SLDPRT
19.1 x 1371.6 x 38.1 mm

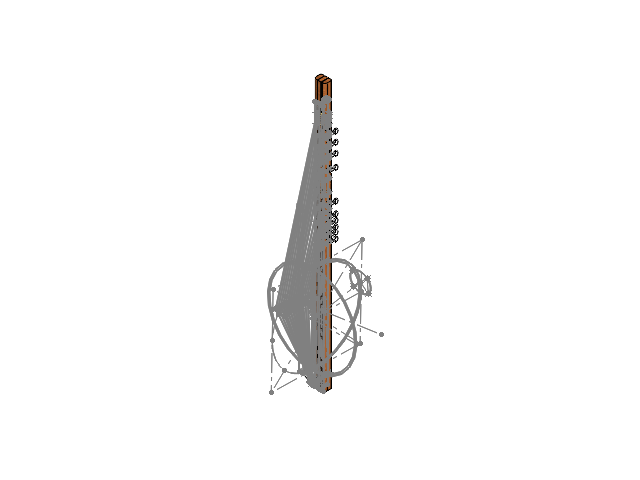
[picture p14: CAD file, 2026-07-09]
cad-recovered-2026-07-04/cad/KOR-000_KoraNeck.SLDASM
KOR-000-LaminateNeck
KOR-000-LaminateNeckMirror
KOR-000-LaminateBottom
KOR-000-LaminateTop
7815K21_Multipurpose Flanged Sleeve Bearing
3025T53_Routing Ringbolt
90611A119_Screw-Mount Nut
Kora_String_Tuner x 10
Kora_String_Tuner_Nut x 21
Kora_String_Tuner_Washer x 21
BrassRod3-16 x 21
Kora_String_TunerMirror x 11

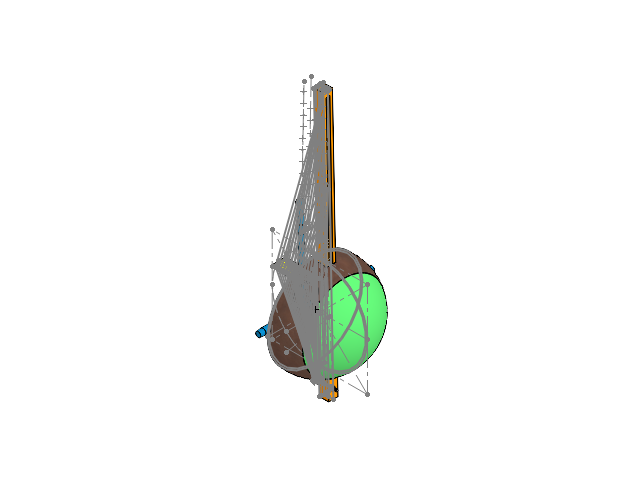
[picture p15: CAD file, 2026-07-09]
cad/KOR-000_KoraHarp.SLDASM
KOR-000_MasterLayout
KOR-000-Gourd
KOR-000-Neck
KOR-000-Crossbar
KOR-000-Handle x 2
KOR-000-Membrane
KOR-000-BridgePad
KOR-000-Bridge
3025T53_Routing Ringbolt

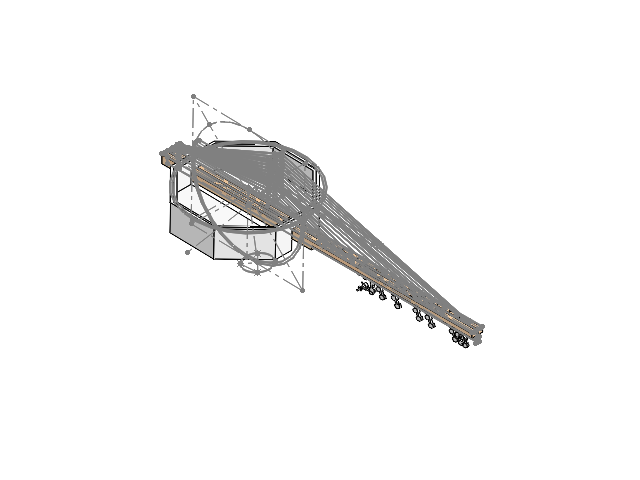
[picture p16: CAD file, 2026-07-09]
cad/neck2_cnc/KOR-NECK2.SLDASM
KOR-000_MasterLayout
KOR-NECK-GlueUp
Kora_String_TunerMirror x 10
Kora_String_Tuner_Nut x 11
Kora_String_Tuner_Washer x 11
Kora_String_Tuner
Musiclily Pro 14mm bass string ferrule x 2
Travel Kora Body

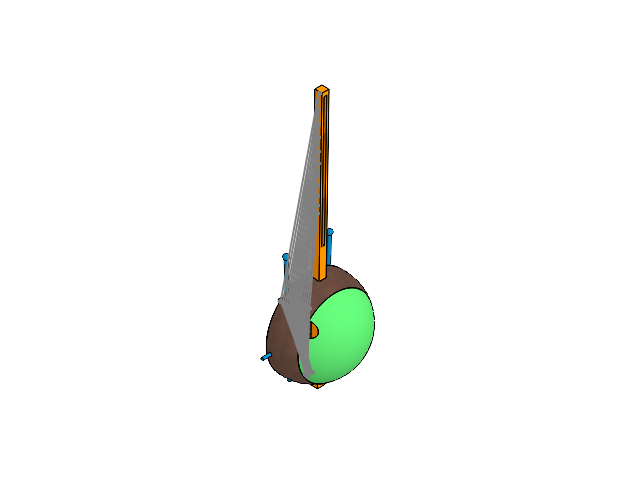
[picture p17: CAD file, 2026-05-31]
cad-recovered-from-stash-20260518/cad/KOR-000_KoraHarp.SLDASM
KOR-000-Gourd
KOR-000-Neck
KOR-000-Crossbar
KOR-000-Handle x 2
KOR-000-Membrane
KOR-000-BridgePad
KOR-000-Bridge
7815K21_Multipurpose Flanged Sleeve Bearing x 2
KOR-000-Eyebolt

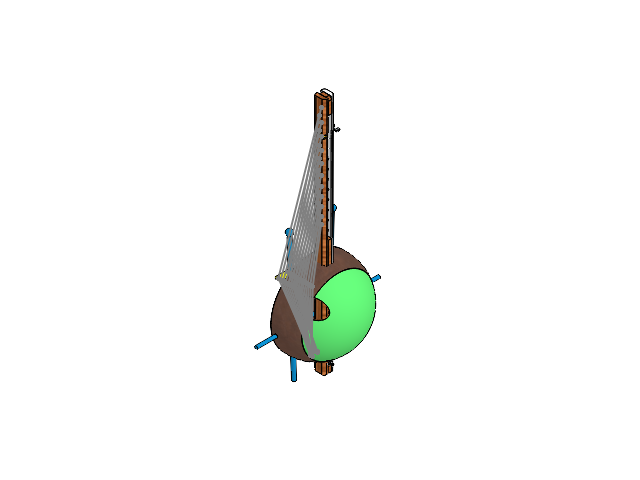
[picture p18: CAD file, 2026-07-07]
cad-recovered-2026-07-04/cad/KOR-000_KoraHarp.SLDASM
KOR-000-Gourd
KOR-000-Crossbar
KOR-000-Handle x 2
KOR-000-Membrane
KOR-000-BridgePad
KOR-000-Bridge
7815K21_Multipurpose Flanged Sleeve Bearing x 3
KOR-000-Eyebolt
KOR-000-LaminateNeck
KOR-000-LaminateBottom
KOR-000-LaminateTop
8953K43_Ultra-Machinable 360 Brass Rod x 21
3014T63_Steel Eyebolt with Shoulder - for Lifting
KOR-000-LeftHardware
90596A280_Steel Round-Base Weld Nut
MirrorKOR-000-LaminateNeck
MirrorKOR-000-LeftHardware

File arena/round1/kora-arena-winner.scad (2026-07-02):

// MakerBench Code-CAD Arena: Kora (21-string West African bridge harp)
// Seed: 0
// Parametric assembly of a multi-part kora.
// All dimensions in millimeters.

// --- Parametric Dimensions ---
bowl_diameter_mm = 516;
bowl_depth_mm = 249;
neck_length_mm = 1300;
string_count = 21;

// --- Helper Functions ---
// Euclidean distance for 3D coordinates
function dist(p1, p2) = sqrt((p1[0]-p2[0])*(p1[0]-p2[0]) + (p1[1]-p2[1])*(p1[1]-p2[1]) + (p1[2]-p2[2])*(p1[2]-p2[2]));

// --- Helper Modules ---
// Renders a cylindrical line/string between two points
module draw_string(A, B, r=0.5) {
    dir = B - A;
    h = sqrt(dir[0]*dir[0] + dir[1]*dir[1] + dir[2]*dir[2]);
    if (h > 0) {
        theta = atan2(sqrt(dir[0]*dir[0] + dir[1]*dir[1]), dir[2]);
        phi = atan2(dir[1], dir[0]);
        translate(A) {
            rotate([0, theta, phi]) {
                cylinder(r = r, h = h, $fn = 4);
            }
        }
    }
}

// --- Component Modules ---

// 1. Gourd Resonator Bowl & Soundboard Skin
module bowl(dia=bowl_diameter_mm, dep=bowl_depth_mm) {
    r = dia / 2;
    wall_thickness = 12;
    
    // Hemispherical gourd shell
    color("SaddleBrown") {
        difference() {
            // Outer scaled hemisphere (bowl_depth is slightly shallower than radius)
            scale([dep/r, 1, 1]) {
                difference() {
                    sphere(r = r, $fn = 80);
                    // Slices the sphere to keep only the negative X hemisphere (the bowl body)
                    translate([r, 0, 0]) cube(r * 2, center = true);
                }
            }
            
            // Inner scaled hemisphere for hollowing the shell
            scale([(dep - wall_thickness)/r, (r - wall_thickness)/r, (r - wall_thickness)/r]) {
                difference() {
                    sphere(r = r, $fn = 80);
                    translate([r, 0, 0]) cube(r * 2, center = true);
                }
            }
            
            // Side Soundhole (circular cutout typical of calabash gourds)
            translate([-dep * 0.6, 140, 100]) {
                rotate([0, 90, 45]) {
                    cylinder(r = 45, h = 100, center = true, $fn = 40);
                }
            }
            
            // Neck pass-through cutouts
            translate([-22, 0, 0]) {
                cylinder(r = 19, h = dia * 2, center = true, $fn = 30);
            }
            
            // Handle pass-through cutouts
            translate([-15, -120, 0]) cylinder(r = 12.5, h = dia * 2, center = true, $fn = 20);
            translate([-15, 120, 0]) cylinder(r = 12.5, h = dia * 2, center = true, $fn = 20);
        }
    }
    
    // Skin Soundboard cover (wheat colored animal skin stretched flat over the opening)
    color("Wheat") {
        translate([0, 0, 0]) {
            rotate([0, 90, 0]) {
                cylinder(r = r - 2, h = 3, center = true, $fn = 80);
            }
        }
    }
    
    // Decorative brass tacks holding the skin to the gourd
    color("Gold") {
        tack_count = 38;
        for (i = [0 : tack_count - 1]) {
            angle = i * (360 / tack_count);
            y_pos = (r - 8) * cos(angle);
            z_pos = (r - 8) * sin(angle);
            // Omit tacks near neck exits and soundholes
            if (abs(z_pos) > 35 && (y_pos < 100 || z_pos < 50)) {
                translate([1.5, y_pos, z_pos]) {
                    rotate([0, 90, angle]) {
                        cylinder(r1 = 5, r2 = 3, h = 4, center = true, $fn = 12);
                    }
                }
            }
        }
    }
}

// 2. Neck with Tuning Rings (Konso)
module neck(length=neck_length_mm, diameter=36) {
    r = diameter / 2;
    
    // Main neck pole (runs parallel to the soundboard, offset to pass through the bowl)
    color("Sienna") {
        translate([-22, 0, 300]) {
            translate([0, 0, -650]) {
                cylinder(r = r, h = length, $fn = 40);
            }
        }
    }
    
    // Traditional leather tuning rings (wrapped Konso)
    color("DarkSlateGray") {
        ring_spacing = 25;
        start_z = 350;
        for (i = [0 : 20]) {
            z_pos = start_z + i * ring_spacing;
            translate([-22, 0, z_pos]) {
                rotate([0, 0, i * 17]) {
                    difference() {
                        cylinder(r = r + 6, h = 12, center = true, $fn = 24);
                        cylinder(r = r - 0.5, h = 14, center = true, $fn = 24);
                    }
                }
            }
        }
    }
    
    // Neck top decorative finial
    color("Tan") {
        translate([-22, 0, 950]) {
            cylinder(r1 = r, r2 = r + 4, h = 20, $fn = 24);
            translate([0, 0, 20]) sphere(r = r + 4, $fn = 24);
        }
    }
}

// 3. Vertical Notched Bridge
module bridge(height=180, thickness=10) {
    // Bridge stands on the soundboard (starts at x=0, extends in +x direction)
    // The plate lies along YZ plane with notches carved on left/right outer edges.
    
    color("BurlyWood") {
        difference() {
            // Tapered vertical bridge body
            translate([0, 0, -thickness/2]) {
                linear_extrude(height = thickness) {
                    polygon(points = [
                        [-10, -50], 
                        [0, -45],
                        [height - 30, -35], 
                        [height, -25],
                        [height, 25],
                        [height - 30, 35],  
                        [0, 45],
                        [-10, 50]   
                    ]);
                }
            }
            
            // Central ornamental cutout
            translate([height/2, 0, 0]) {
                cube([height/3, 16, thickness + 2], center = true);
            }
            
            // Left String Notches: 11 notches spaced along the left side
            for (i = [0 : 10]) {
                x_pos = 35 + i * 13;
                y_pos = -35 + i * 0.9;
                translate([x_pos, y_pos, 0]) {
                    cylinder(r = 1.5, h = thickness + 2, center = true, $fn = 8);
                }
            }
            
            // Right String Notches: 10 notches spaced along the right side
            for (i = [0 : 9]) {
                x_pos = 40 + i * 14;
                y_pos = 35 - i * 1.0;
                translate([x_pos, y_pos, 0]) {
                    cylinder(r = 1.5, h = thickness + 2, center = true, $fn = 8);
                }
            }
        }
    }
    
    // Wooden base wedge/pad distributing pressure on the soundboard skin
    color("SaddleBrown") {
        translate([3, 0, 0]) {
            cube([6, 110, 24], center = true);
        }
    }
}

// 4. Handles and Crossbar
module crossbar_or_handles() {
    handle_len = 650;
    handle_rad = 11;
    handle_x = -15;
    handle_y_offset = 120;
    
    // Hand grips: Two parallel sticks passing through the gourd skin
    for (y_dir = [-1, 1]) {
        // Wooden support rods
        color("Sienna") {
            translate([handle_x, y_dir * handle_y_offset, -230]) {
                cylinder(r = handle_rad, h = handle_len, $fn = 30);
            }
        }
        // Leather grip wraps on the handles
        color("DarkRed") {
            translate([handle_x, y_dir * handle_y_offset, 50]) {
                cylinder(r = handle_rad + 1.5, h = 250, $fn = 30);
            }
        }
    }
    
    // Crossbar: Perpendicular bracing rod passing under the neck/handles
    color("Sienna") {
        translate([-32, 0, 60]) {
            rotate([90, 0, 0]) {
                cylinder(r = 10, h = 530, center = true, $fn = 24);
            }
        }
    }
}
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

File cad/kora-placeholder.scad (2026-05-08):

// Kora-inspired prototype placeholder geometry.
// Not a final CAD model. Source values from kora-design-table.xlsx.

bowl_diameter = 20.3;
bowl_depth = 9.8;
neck_length = 51.2;
bridge_height = 6.0;

module bowl_shell() {
  scale([bowl_diameter/2, bowl_diameter/2, bowl_depth])
    difference() {
      sphere(1, $fn=96);
      translate([0,0,0.08]) scale([0.86,0.86,0.86]) sphere(1, $fn=96);
      translate([-2,-2,-2]) cube([4,4,2]);
    }
}

module neck() {
  translate([-0.45,-0.45,-bowl_depth*0.15])
    cube([0.9,0.9,neck_length]);
}

module bridge() {
  translate([2.6,-0.35,0.6])
    linear_extrude(height=0.75)
      polygon(points=[[0,0],[2.5,0],[1.8,bridge_height],[0.7,bridge_height]]);
}

bowl_shell();
neck();
bridge();

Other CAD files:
cad-recovered-2026-07-04/cad/neck_cnc/KOR-NECK-Front-Drill.dxf
cad-recovered-2026-07-04/cad/MirrorKOR-000-LaminateNeck.SLDPRT
cad-recovered-2026-07-04/cad/neck_cnc/KOR-NECK-Side-LEFT.dxf
cad-recovered-2026-07-04/cad/neck_cnc/KOR-NECK-Side-RIGHT.dxf
cad-recovered-2026-07-04/cad/BrassRod3-16.SLDPRT
cad-recovered-2026-07-04/cad/KOR-000-LaminateBottom.SLDPRT
cad-recovered-2026-07-04/cad/KOR-000-LaminateNeck.SLDPRT
cad-recovered-2026-07-04/cad/KOR-000-Neck.SLDPRT
cad-recovered-2026-07-04/cad/KOR-000_KoraNeck.SLDDRW
cad-recovered-2026-07-04/cad/KOR-000_MasterLayout.SLDPRT
cad-recovered-2026-07-04/cad/neck_cnc/KOR-NECK-Back-Channel.dxf
cad-recovered-from-stash-20260518/cad/3032T43_316 Stainless Steel Eyebolt with Nut.SLDPRT
cad-recovered-from-stash-20260518/cad/7815K21_Multipurpose Flanged Sleeve Bearing.SLDPRT
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

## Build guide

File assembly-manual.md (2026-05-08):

# Assembly Manual

## Safety Position

Build this as a staged prototype. Do not bring the instrument to full tension until the bowl, neck, tail anchor, bridge, and head pass the validation gates. Wear eye protection during load tests and string pull-up. Keep hands and face out of the string plane.

## Tools

- table saw with accurate miter sled
- band saw, drill press, clamps, rasps, files, sanding blocks
- calipers, ruler, square, bevel gauge, tuner, scale or load cell
- optional laser cutter for bridge/string templates
- optional lathe for handles

## Stage 1 - Workbook And Drawing Hold Point

1. Open `kora-design-table.xlsx` and confirm the interpreted cell map in `design.md`.
2. Add labels to the workbook or keep a printed cell map beside the shop packet.
3. Decide whether the first build is `KORA-21-MULE` low-tension or `KORA-21-ROOT`.
4. Do not order final strings until the string safety check is revised with actual supplier unit weights.

Hold point: `VAL-001` through `VAL-004`.

## Stage 2 - Segmented Bowl

1. Mill straight, consistent hardwood strips for ring segments.
2. Set the miter sled to 15 deg for 12-segment rings.
3. Cut one scrap ring first and dry-fit it without force.
4. Cut 168 bowl segments only after the test ring closes cleanly.
5. Glue rings one at a time, checking flatness after each ring.
6. Stack 14 rings to the 9.8 in workbook depth, preserving centerline references.
7. Shape the bowl gradually; leave extra wall thickness until head and neck interfaces are finalized.

Hold point: inspect glue lines and ring closure before shaping the final outer profile.

## Stage 3 - Rim And Head Interface

1. Set the miter sled to 11.25 deg for the 16-segment rim.
2. Build a test rim ring and confirm it mates evenly to the bowl.
3. Round every membrane contact edge. No sharp corner should touch hide or synthetic head material.
4. Choose tacks, lacing, or hoop retention only after a head-material sample test.
5. Install the head with even tension and document moisture/temperature conditions.

Hold point: no bridge installation until the membrane is stable and inspected.

## Stage 4 - Neck And Tail Load Path

1. Shape the 51.2 in neck blank or internal spine with generous radii at stress transitions.
2. Confirm the neck passes through or mechanically bypasses the bowl wall so string load does not rely on thin shell alone.
3. Fit the tail anchor ring/bar with rounded contact surfaces.
4. Proof-load the neck and tail assembly with shielding before stringing.

Hold point: no strings until `VAL-008` and `VAL-009` pass.

## Stage 5 - Bridge Prototype

1. Cut the first bridge oversized from dense hardwood.
2. Mark the bridge centerline, bank faces, foot location, and 21 notches using the bridge template.
3. Keep the bridge foot broad for the first pressure test.
4. Test leather/cork/felt foot pads under staged load.
5. Photograph bridge lean and head deflection at each load increment.

Hold point: bridge must not rock, cut the head, or show progressive lean.

## Stage 6 - Low-Tension Stringing

1. Install only a partial string set first, alternating banks to balance load.
2. Bring strings to 25 percent of intended tension.
3. Wait, inspect, and photograph the head, bridge, neck, and tail.
4. Increase to 50 percent only if no movement is observed.
5. Use the `KORA-21-MULE` schedule before attempting full pitch.

Hold point: revise string gauges before any full-pitch demonstration.

## Stage 7 - Tuning And Measurement

1. Record room temperature and relative humidity.
2. Measure each string frequency with a tuner.
3. Measure bridge position, head deflection, and neck deflection.
4. Record results in `validation.csv`.
5. Update `kora-design-table.xlsx` with measured corrections.

## Stage 8 - Optional Pickup

1. Do not drill the bowl for electronics until the acoustic prototype passes.
2. Test removable piezo placement first.
3. Compare acoustic and pickup response.
4. Add an access plate only if it does not weaken the load path.

## Maintenance Notes

- Recheck bridge lean and tail hardware before each session.
- Detune after tests if the head or neck shows continuing movement.
- Keep the instrument away from extreme humidity swings until the head material is characterized.

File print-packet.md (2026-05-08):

# Kora-Inspired Prototype Print Packet

## Cover

Root-mode v4.3 build packet for a 21-string kora-inspired hybrid prototype. Status: private review. Source workbook: `kora-design-table.xlsx`.

## Quick Start

1. Read `design.md` and `risks.md`.
2. Confirm workbook cell meanings before cutting material.
3. Revise string schedule before full-tension stringing.
4. Build the low-tension mule path first.
5. Keep cultural/provenance language under review before public release.

## Design Summary

The workbook indicates a 20.3 in diameter, 9.8 in deep segmented bowl, a 51.2 in neck, string lengths from 8.7 to 31.1 in, and a 21-string Mersenne-Taylor schedule. The design uses a segmented wood bowl as a practical prototype substitute for calabash and treats the bridge/head response empirically.

## Public-Safety Notes

The current string model has high percent-break values for the treble strings. Do not string to full pitch until revised with real string data. Proof-load the neck and tail anchor. Shield the bridge/string plane during pull-up.

## Cultural Notes

This packet should describe the project as kora-inspired and prototype-focused. It should not claim traditional authority or authenticity. Cultural review is required before publication.

## File Map

See `README.md` for the full artifact map. Shop-critical files are `design.md`, `bom.csv`, `sourcing.csv`, `cut-list.csv`, `validation.csv`, `assembly-manual.md`, `drawing-brief.md`, and `risks.md`.

## Shop Hold Points

- workbook traceability
- string percent-break check
- miter sled dry-fit
- rim/head sample test
- neck/tail proof load
- bridge/head staged pressure test
- partial low-tension stringing
- ergonomic hand-post mockup

## CSV Attachments

Print `bom.csv`, `sourcing.csv`, `cut-list.csv`, and `validation.csv` as separate table pages for shop use. Keep measured values and notes on the printed validation sheet, then update the source CSV.

## RFQ

Use `supplier-rfq.md` for hardwood, head material, string, metal hardware, and electronics supplier conversations. Do not treat planning estimates as current prices.

## Drawing Attachments

The drawings currently in `drawings/` are schematic placeholders. They are useful for review but not CNC-ready.

## Release Decision

Recommendation: keep private pending cultural and safety review.

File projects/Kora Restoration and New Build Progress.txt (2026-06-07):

Kora Restoration and New Build Progress on June 6th, 2026

The other weekend at Ethan's birthday party, we had an arts and craft session where I was able to make a bunch of progress on the Kora restoration.

- I measured a all of things and wrote down the dimensions, I still have to transfer those from paper into the electronic file. 
- I took a bunch of photos before taking it apart. 
- I measured all the strings (2 or 3 were missing) and then removed them all as one item while still attached to the old tail anchor which is going to be replaced anyway. 
- On May 20th I placed an order for new kora strings with kumbengokoras.com (Sarah Welch <sarahwelchpottery@gmail.com>), they got delayed by two weeks but hopefully will be shipping by June 9th. 
- I have been watching some kora and gourd banjo making videos on youtube and learned a few things I'd like to apply to this build 
- Use sandpaper on the gourd exterior
- Use a steel or brass wire brush on the interior of the gourd to remove any excess dried out gourd pulp.
- Apply a layer of fiber glass to the gourd interior to reinforce and strengthen the gourd for longevity.
- Use a big belt sander (or parking lot asphalt surface) to smooth out the gourd rim after cutting off the top.
- Use a rasp or file or router bit to apply a gentle fillet upon the bearing edge for cowskin membrane longevity.
- Apply a shellac or other finish that will cause the grain and color to pop while still providing durable protection.
- There may be some benefit to soaking the new cowskin in room temp coffee to add a coffee stain and perhaps the tannin content in the coffee adds some beneficial properties to the cowskin.
- I have a couple cowskins in my shopping cart with https://djembedrumsandskins.com but I haven't purchased yet. 28" Hairless South American Cow Rounds.
- Prestretch the cowhide during soaking to encourage a snug tight fit after being tacked onto the gourd and dried.
- My restoration kora has half-moon reliefs cut into the gourd rim such that the wooden crossbar is recessed
- Nail holes to be filled, potentially with wood filler?
- The gourd has two cracks which must have been present during construction because I discovered two reinforcing sutures that were sewn into the gourd before the original cowhide was applied. Unfortunately, one of those cracks goes from the gourd rim to the top neck hole. Several of the videos I've watched have come up with techniques to reinforce the rim from the inside including the usage of bamboo strips or aluminum flatbar. I have been considering using 3003 aluminum flatbar 1/8" x 1" x 72" Mcmaster part 9134K11. But, I'm not sure how to deal with the half-moon releifs since they interrupt the rim's circumference, maybe I could cut a reliefs in the wooden cross bar for the aluminum flatbar to remain continuous around the ID circumference.
- I am planning on wood turning the original crossbar and two handle bars on a wood lathe. The handles are roughly 1.2" diameter which feel too large for my pinky and ring fingers to grip while playing, turning them down to 0.875-1.0" will make them more ergonomic and provide a smoother fresh surface to apply a wood finish. The kora neck is 49" which is too long for the wood lathe at Maker Nexus, I'll likely manually sand that by hand.
- I plan to reuse the original bridge and bridge foot though they are rough cut and I plan to put them through the drum sander for a more quality surface and texture. 
- I've removed most of the old nails from the old cowhide but there are still a handfull of stubborn ones that need removing. These old nails will not be reused, I will want to get some new tacks.
- The holes in the gourd for the neck are oversized at around 2.25" diameter, but the neck shaft itself is about 1.85" diameter x 49" long, so I'll want to figure out a way to fill that gap and ensure a good fit between the gourd and the neck shaft.
- The half-moon reliefs are also slightly oversized for the crossbar, and will be even more oversized once I woodturn a fresh surface onto that crossbar. This will need a similiar solution as the neck hole diameter mismatches.
- I'm thinking about putting some kind of grippy and protective foot on the bottom of the neck shaft where it contacts the ground while playing. The bare wooden end feels a bit clunky and like it could scratch up the floor where being played.
- Photo albums here in these folders: "C:\Users\Tony\Documents\GitHub\instruments\strings\kora\projects\restoration photo album" and "C:\Users\Tony\Documents\GitHub\instruments\strings\kora\projects\new kora build" These will need to be committed. 
- I kept the old cowskin since it can be used for other projects, I think I only counted 20 tuning rings so I'll need to make another one. I might even make an entirely new set tuning rings from this old cowskin. 
- When I was measuring the strings before taking them off and I was filling out the measurement packet, I was not sure that I properly attributed string lengths to their proper number and keys. My method was that all 11 strings on the left were odd numbers and all 10 strings on the right were even numbers (top left string is #21, bottom right string is #2). This may require a bit of sorting out when restringing the kora.
- I also made a second eBay purchase for a 17" diameter African Kettle gourd which will be used for the new kora built from scratch. I did receive the tuning hardware already. Hopefully my fresh package of strings will have enough to restring two koras, if not then I'll likely reverse engineer the string package and source my own strings instead of buy a second package. 
- I still need wood for the new kora's handles, neck, crossbar, bridge and bridge foot.
- I collected roughly 320 African kettle gourd seeds (estimated by mass), and I would really love to grow some to build future koras and gourd banjos. I'm going to need a community garden plot or friends and family to grow these for me.

Lots of strings to pull on here, pun intended :-)

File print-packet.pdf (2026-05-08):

## Kora-Inspired Prototype Print Packet

Private review. Source workbook: kora-design-table.xlsx.

Kora root-mode packet - private review

## Design Summary

20.3 in segmented bowl, 9.8 in depth, 51.2 in interpreted neck, 21 strings from workbook schedule.

## Safety Holds

Revise string percent-break, proof-load neck/tail, test bridge/head pressure, use low-tension mule first.

## Cultural Holds

Use kora-inspired/prototype language. Do not claim authenticity or traditional authority. Seek review before publication.

## Build Workflow

Workbook audit, segmented bowl, rim/head, neck/tail proof-load, bridge prototype, low-tension stringing, measurement.

## Validation

Record string frequency, bridge lean, head deflection, neck deflection, humidity, and cultural-review status.

## Release Recommendation

Keep private pending cultural review, safety validation, measured prototype data, and owned visuals.

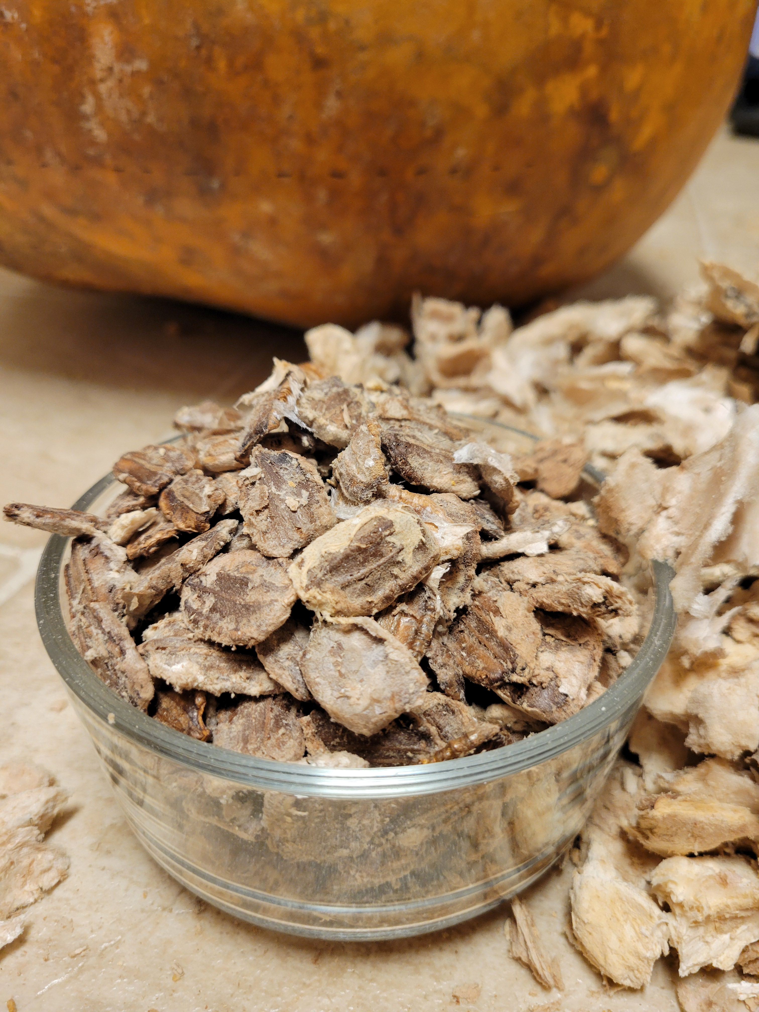
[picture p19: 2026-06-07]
projects/new kora build/20260530_212528.jpg

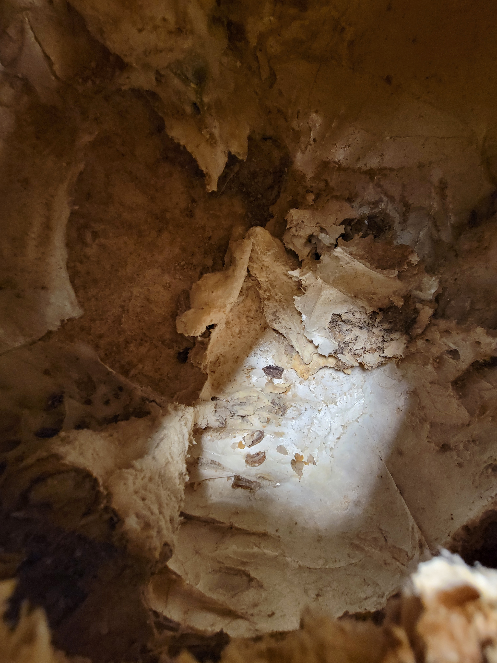
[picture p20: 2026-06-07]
projects/new kora build/20260530_205225.jpg

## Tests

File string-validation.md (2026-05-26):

# String Validation Gate - Kora

Status: blocker for full stringing and build-ready claims.

This slice turns the current workbook-derived string schedule into an explicit
validation gate. It does not approve a purchase-ready string set. It records
which rows exceed the practical prototype percent-break target and what must be
measured before the repo can move beyond L2 private review.

## Current Modeled Risk

Source: `design.md` current string schedule, derived from
`kora-design-table.xlsx` and the Mersenne-Taylor model.

- Total planned load from the current 8.0 to 14.0 lbf ramp is 231 lbf.
- Nylon strings 1-8 model above the 70 percent prototype break target.
- Nylon string 9 models at 69.3 percent, close enough to require supplier data
  before approving the set.
- Wound strings 18-21 depend on an effective-density factor, not verified
  manufacturer unit-weight data.
- Wound strings 18, 19, and 21 also model above the 70 percent check, but the
  exact value must not be treated as authoritative until real string data is
  available.

See `string-break-risk.csv` for the row-by-row risk register.

## Hold Points

- Do not order final strings from the current schedule.
- Do not pull all 21 strings to full pitch.
- Do not call the packet build-ready, safe for full stringing, or fabrication
  authoritative.
- Use staged low-tension mule tests with shielding until the string schedule is
  revised and measured or supplier-backed string data exists.

## Promotion Requirements

Before full stringing:

1. Replace the ideal nylon and wound-string model with actual supplier diameter,
   unit weight, recommended tension, and break/tensile data.
2. Revise treble pitch, scale length, material, or target tension until all
   nylon rows sit below the chosen prototype safety target with margin.
3. Replace the wound-string effective-density factor with manufacturer data or
   measured mass-per-length data.
4. Re-run the percent-break table and update `string-break-risk.csv`.
5. Keep the neck/tail/bridge/head proof-load gates in `validation.csv` open
   until physical tests pass.

## Suggested Low-Tension Mule Path

Use `KORA-21-MULE` from `family-spec.csv` as the next safe path. That mule keeps
the geometry visible for bridge/head behavior while reducing the immediate
string-break hazard. Treat any mule stringing as a measurement fixture, not as a
performance instrument.

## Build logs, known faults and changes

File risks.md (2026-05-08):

# Risks

## Cultural And Public-Release Risks

- The kora is a culturally situated West African instrument associated with Mande/Mandinka traditions and jali/griot musicianship. A public repo can easily overclaim authority even when the engineering is careful.
- The segmented wooden bowl is a practical prototype substitute and must not be described as a traditional calabash.
- Public marketing language should avoid `authentic`, `traditional replica`, `improved`, or `modernized kora` unless reviewed and approved by qualified cultural collaborators.
- Visuals should not copy specific makers' instruments without permission.

Mitigation: keep private until review; add explicit provenance notes; invite review from a knowledgeable kora player/maker or cultural advisor.

## String Tension Risks

- Current workbook calculations put several treble strings near or above practical nylon break targets.
- Wound bass string modeling uses an effective density factor and may not match real strings.
- String breakage can be high energy, especially near the player's face and hands.

Mitigation: use low-tension mule schedule first; require real string unit-weight data; use shields and staged pull-up.

## Bridge Risks

- The 6 in bridge is tall relative to the head and can rock under asymmetric load.
- Notches can concentrate stress or create string buzz if spacing is wrong.
- A narrow bridge foot can dent or tear the membrane.

Mitigation: use sacrificial bridge prototypes; test foot pads; photograph lean; increase footprint before final bridge.

## Resonator And Head Risks

- A segmented wooden bowl will not behave exactly like calabash.
- Hide head humidity response can change tension and bridge loading.
- Tacks or lacing can split the rim or tear the membrane.

Mitigation: test material samples; round all contact surfaces; record humidity; do not make acoustic claims before measurement.

## Neck And Joint Risks

- Total string load can exceed 200 lbf if the workbook tension ramp is used literally.
- A bowl-wall-only joint is not acceptable for the first full-tension prototype.
- Tail anchor edges can cut strings or deform under load.

Mitigation: continuous through-neck or internal spine; load-rated rounded tail hardware; proof-load at 1.5x planned total tension.

## Ergonomic Risks

- Hand posts may force wrist extension if bridge/bank spacing is not player-tested.
- Tuning access may be awkward or unsafe under tension.
- Instrument balance may shift if electronics or a heavy segmented bowl is added.

Mitigation: cardboard/wood mockup first; 15 minute player comfort test; measure reach and posture before drilling final handle holes.

## Release Recommendation

Private pending review. Candidate for public release only after safety validation, measured prototype data, final cultural wording review, and replacement of placeholder drawings/images.

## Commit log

2026-05-02 Initial scaffold: Kora
    [kora-design-table.xlsx]
2026-05-09 feat: add learn-to-play/ starter songbook — kora (string family, R4) (#3)
2026-05-20 Add kora string break-risk validation gate (#4)
    [string-break-risk.csv, validation.csv]
2026-05-29 [kora] Add V5 build-packet surface: VOR + mcp-log + status line (Refs #1) (#5)
    - README: add Status: L2 V5 build-packet candidate
    - visual-output-register.csv: register all existing artifacts including
    pre-existing kora-placeholder.scad as CAD-001
    - cad/mcp-session-log.md: V5 provenance trail for this sprint pass
    Open L3 gates: cultural review, string-safety, measured prototype data,
    DXF/hero render.
    [visual-output-register.csv]
2026-05-31 wolfram-rename(kora): unique {slug}-starter.wl + dedupe + ref fixes (cloud-sync naming) (#6)
    [3032T43_316 Stainless Steel Eyebolt with Nut.SLDPRT, 7815K21_Multipurpose Flanged Sleeve Bearing.SLDPRT, 7815K24_High-Strength 932 Bronze Flanged Sleeve Bearin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]
2026-05-31 Add image-gen concept prompt; wire explorer images
2026-06-07 Add measurements as CSV (robust to sync); string 21 corrected F3->F2 (Mande bass tonic), 0.026in diameters, braid/twist notes
    [condition-restoration-log.csv, dimensions.csv, instructions.csv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]
2026-06-23 feat(wolfram): deploy interactive model + live explorer embed (#8)
    * feat(wolfram): deploy interactive model + live explorer embed
    CloudDeploy Manipulate to Wolfram Cloud (Public-Execute); regenerate
    explorer.html with live iframe. Refs tonykoop/instrument-maker#196
    * feat(wolfram): wire live explorer embed in explorer.html (Refs #196)
    ---------
2026-07-02 feat(arena): Code-CAD Arena Round 1 winning model (generated, not a master)
    Winning blind-vote candidate from makerbench-hwe Code-CAD Arena round1,
    exported by 'makerbench arena export-winners'. See arena/round1/provenance.json
    for entrant, votes, and gate sub-scores. AI-generated artifact - never a
    measured master or validated build packet.
    Claude-Session: https://claude.ai/code/session_01Ew72pzuM36NwvCSbcruyxs
    [kora-arena-winner.scad, kora-arena-winner.stl]
2026-07-02 feat(arena): Code-CAD Arena Round 2 winning model (generated, not a master)
    Blind-vote winner from makerbench-hwe round2 (claude-code-fable, 4 vote-wins,
    0.917 objective). See arena/round2/provenance.json.
    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
    [kora-arena-winner.scad, kora-arena-winner.stl]
2026-07-02 feat(arena): Adam plugin SolidWorks kora assembly (generated draft, needs changes)
    Third arena modality: Adam plugin driving SolidWorks. 8 native parts +
    assembly, STL/STEP exports (mm), gate 0.833 in makerbench-hwe round3 as
    entrant adam-solidworks. Generated draft — not a measured master.
    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
    [Kora_Assembly.SLDASM, Kora_Assembly.STEP, Kora_Assembly.STL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]
2026-07-07 cad updates
    [KOR-000-Bridge.SLDPRT, KOR-000-BridgePad.SLDPRT, KOR-000-Crossbar.SLDPRT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]
